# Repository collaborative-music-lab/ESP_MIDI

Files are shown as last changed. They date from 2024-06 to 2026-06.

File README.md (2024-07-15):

# ESP_MIDI
This repo contains hardware and software components for creating MIDI controllers using the ESP32-s3 microcontroller. The native USB port on the s3 allows for class-compliant MIDI devices which should be recognized natively by any computer.
The repo consists of:
1. **PCB**: A PCB design created in KiCad, along with PDF’s of the board and schematic
2. **Enclosure**: 3d-printable faceplates and knobs
3. **Software**: Arduino-based software for programming your MIDI controller
Each subfolder contains its own readme with additional information for each stage
# FYI / FAQS
There are several things you need to know.
### Allowing for class-compliant midi
To let ESP32-s3 appear as a class compliant device, you *must* set the ‘USB Mode’ for the board as “USB OTG(TinyUSB)”. You can find this setting in the Arduino *Tools* menu.
### Reprogramming after setting USB OTG
Once the board is set to USB OTG mode it won’t show up in Arduino as a Serial device. In order to reprogram the device you must manually hold down the ‘boot’ button on the ESP32-s3, and then press press and release the ‘reset’ on the ESP32-s3.
### Allowing for Serial debugging
In order to use serial.print debugging, you *must* set “USB CDC on boot” to “enabled”. You can find this setting in the Arduino *Tools* menu.

# Components
There are three components to this project:
1. The PCB and electronics assembly
2. The enclosure and mechanical elements
3. The firmware for the ESP-32-S3

Instructions on how to complete the project are in the readme's for these three subfolders.

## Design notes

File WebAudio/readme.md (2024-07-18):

# Web Audio using the 21M.080 Web Audio Framework

The 21M.080 Web Audio Framework is a live coding environment for working with audio in web browsers. This folder contains four files:
* SimpleSynth.txt: Gives a simple example of how to create a synthesizer
* Rumble.txt: A more complex synthesizer, which also includes a basic sequencer
* drum_sampler_midi.txt: An example of a drum sampler controller by our MIDI controller
* polyphonic_synth_midi.txt: An example using our MIDI controller to trigger four different pitch sequences

## Working with the framework

The website includes a codebox on the left hand side. You can execute code in three ways:
* Hitting the 'run' button will execute the whole codebox, from top to bottom.
* Putting your mouse cursor on a line and hitting option-return will execute a single line of code
* Putting your mouse cursor on a line and hitting shift-option-return will execute a block of code
  * Code blocks are separated by blank lines.
 
## Debugging
It can be really helpful to use the javascript console to see key information and any errors as you run code. 
* The javascript console can be found by going to the view menu, and then developer->javascript console. Or you can just type option-command-j

# Using a midi controller 
To use your midi controller with the framework: 
* copy and paste one of the files that say midi in the name into the codebox
* Hit 'run'
* Open the javascript console. If there are any errors try refreshing and running again
* With your MIDI controller plugged in, look for the midi inputs in the console. Your controller will show up as Wifiduino or something similar.
* Note the number associated with your controller in the list of inputs.
* In the codebox, there is a line `setMidiInput(2)`. Change the `2` to whatever number is associated with your controller and execute that line (option-return)
* Your controller should start triggering sounds!

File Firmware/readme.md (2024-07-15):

# Arduino Setup
Download the Arduino IDE from Arduino.cc
* there is a web app for Arduino but it won't support the ESP32 so we can't use it.

## Add support for ESP32 to Arduino
Add this link to:
* (MacOS) Arduino->settings->additional board manager URLs
* (Windows) File->preferences->additional board manager URLs
https://dl.espressif.com/dl/package_esp32_index.json

more info on this here: https://medium.com/@pauljoegeorge/setup-arduino-ide-to-flash-a-project-to-esp32-34db014a7e65

# Firmware
Two sets of firmware are provided

## InputMonitor.ino
This firmware allows you to monitor all of your input in the Arduino Serial Monitor
* MAKE SURE you set “USB CDC on boot” to “enabled”. You can find this setting in the Arduino *Tools* menu. The serial monitor will not work if you do not do this!

Once uploaded, open the serial monitor and you should see data streaming from all the sensors. Play with all of the sensors and make sure the data looks good. Take note of any of the potentiometers whose ranges are backward - we can fix this in the other firmware.

## ESP32_MIDI
This is the main firmware for the project, which sets up native USB-midi support. 

Open the ESP32_MIDI.ino file in the Arduino IDE. The comment at the top of the ESP32_MIDI.ino file should explain most of the code. All of the other files will open alongside the main file.

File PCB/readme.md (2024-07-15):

# PCB and Electronics Assembly

The project consists of:

1. The main PCB, with the ESP32 pre-soldered
2. 4 potentiometers, 2 to place on the PCB and two additional off-board potentiometers with small pcbs.
3. 4 Arcade Buttons
4. An LSM6DS3 IMU breakout board
5. An RGB LED and resistors

## Assembly

Make sure get your enclosure drilled for your faceplate before you mount your PCB to the faceplate in step 9!!!

1. Place two potentiometers on the PCB. Make sure they are flat. It is a good idea to place the potentiometers on a faceplate to make sure they are aligned. Solder the potentiometers in place.
	* the potentiometers go on the opposite side of the PCB from the ESP32 (e.g. the ESP32 is on the bottom, and the potentiometers are on the top).
2. The LED uses 3 resistors with values between 120 and 470 ohm. All resistors may be the same value. Place and solder the resistors. 
3. DO NOT solder the LED yet. We will solder the PCB once we are ready to mount the electronics to the faceplate.
4. Solder the small PCBs to the two off-board potentiometers. The potentiometer pins go in the holes next to the word 'POT'
5. Solder headers to the LSM6DS3 breakout on the side that has 6 holes. Leave the five holes on the other side of the PCB empty.
6. Place the LSM6DS3 breakout into the head holes labelled 'IMU' on the PCB. Make sure the V+ and VIN pins on the PCB and breakout are aligned. Double-check - if you are not confident, ask for help! 
	* The breakout should be on the bottom of the board, the same side as the ESP32
7. Cut wires for connecting the arcade buttons and external potentiometers. You will need 3 groups with different colors:
	* 6 wires for grounds
	* 6 wires for signal
	* 2 wires for V+
8. Solder these wires into the PCB. Note that there are six places for external sensors, each with a ground, V+, and signal pad. You will need to solder each ground and signal (A1-A6) pad, but only two of the V+/3v pads. 
9. Once all of these wires are soldered in it is time to mount the PCB in the faceplate and solder the LED. 
10. Put the LED in the LED holes. The longest leg of the LED goes into the round hole next to the square hole. If you look on the bottom of the PCB you will see one trace connected to the LED holes - that hole is where the long leg goes. 
	* It is a good idea to plug in your ESP32 and test the LED works before soldering it down
	* you will also need to adjust the LED so it fits through the hold in the faceplate before soldering it.
11. Once the LED is soldered you can screw the potentiometers on the PCB to the faceplate. Use a 10mm socket to screw this down.
12. Place the arcade buttons and other potentiometers in the faceplate. Make sure the faceplate fits inside the enclosure
13. Solder the wires to the potentiometers. Look on the small PCB and you will see indications for where G, V+, and Sig go.
14. Solder wires to the Arcade buttons. These just have a ground and signal wire soldered to the two pins. It doesn't matter which pin is ground and which is signal.
15. You are done soldering! Time to program the ESP32 and test your MIDI controller. You might want to hold off on screwing the faceplate down until you have tested all of the sensors. . .

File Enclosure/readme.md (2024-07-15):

# Enclosure

All 3D printed files were created with the free open-source CAD software Blender - download here:

## Faceplates
The enclosure is designed to use a Hammond 1590BB Aluminum enclosure, with a 3D-printed faceplate. Two faceplate designs are provided in the faceplates folder.

## Knobs
The project uses standard 7.3mm knurled potentiometers, and a series of 3D-printed knob designs are available:
1. `_knurledKnobInsert_7.3mm` is a file of a standard knurled potentiometer shaft, and can be used to create your own knob design
2. `knurledKnobDome_20mm-Dome` is a large knurled dome knob
3. `knurledKnobFlatWide_18mm-Circle.stl` and `knurledKnobFlatWide_20mm-Main_body` were created to make it easy to turn a knob with one finger. These designs are full-height and meant to work with standard enclosure.
	* `knurledKnobFlatWide_20mm_pointer-Pointer` is a small shape inset into the top of the above knobs to use as a pointer
4. `knurledKnobFlatWide_20mmTop_rounded-Circle` and `knurledKnobFlatWide_20mmTop-pointA-Circle_001` are half-height knobs, intended to be used with recessed potentiometers. 
	* `knurledKnobFlatWide_20mmTop-pointB-Circle_001` is a pointer for these knobs.
	
## USB-C port
This is a cap meant to be used to cover the hole drilled for the PCB's USB-C jack. It is oversized to allow a cable to pass the the cap.

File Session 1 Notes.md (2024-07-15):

Introduction to music technology and essential concepts
1. Introduction 
   1. Who is a music technologist?
   2. What do we need to know?we will be talking about what sound and music consists of 
   3. I am a musician first and technologist second 
      1. everything you learn will be important whether you are a musician performing with technology or someone creating your own new technology to make music
2. Fundamental concepts
   1. Learning the languageWhat is sound harmonics amplitude frequency 
3. names for pitch, frequency, midinote, chord degree
4. What is an octave frequency, ratios, harmonics, and pitches? ￼
5. Visualization 
6. Frequency spectrum is and frequency responses. ￼
7. Sounds and time envelopes, rolloff, etc. also revert and delay. ￼
8. Playing with synths 
9. ￼ what is digital audio, sampling rate bit depth, audio interfaces 
10. using plug-ins working with EQ and compression ￼￼
11. Mastering using speakers and the entire recording chain. ￼

# Introduction
Who is a music technologist? I would say anyone who is creative, musical ideas are expressed through new electronic or digital systems from any of us. This will involve learning how do use new systems being aware of what the new possibilities are in integrating them into our musical performance practice however, increasingly it is common for musicians to actively create new technologies as part of their creative process. For me, this is one of the most exciting aspects of being a contemporary musician.

Here are some examples of work you might engage in:
* recording music entirely within a digital audio workstation
  * you might use a MIDI controller as an input device, or work solely with your laptop
* building a personal sample library for performance or composition
  * this involves either recording your own sounds, or finding sounds only and processing them
  * your personal musical tastes and goals will cause you to be highly selective, and you will likely manipulate all of the samples in your library to get them to sound just right
* building synthesizers, or other musical instruments, inspired by current instruments
  * many people are inspired by existing instruments, either wanting to improve on them, or combine them, or just build something that you can't get your hands on any other way
* designing new kinds of instruments, inspired by your own ideas
  * sometimes you'll have an idea for a new instrument that you've never seen before. Exploring your own ideas in this way, can be highly satisfying and lead to very unique music.
* designing new forms of musical performance using sensors
  * all hardware instruments rely on sensors to detect gestures. There are lots of sensors out there and also lots of different ways of making mechanical structures to work with the sensors. It can take a long time to get a sensor to feel just right!
* creating tools to generate music
  * AI has gotten a lot of attention for generating music in the past few years, but people have been creating generative music processes for centuries. Many musicians have specific generative processes that they rely on as part of their practice, and get to know extremely well. Generative music does not have to be an all or nothing deal, you can have a generative system create only part of the musical texture, and then control or compose the other parts of yourself. As you can imagine, there are lots of possibilities, and they can be really fun!
* creating tools to analyze music
  * Similarly, there has been a lot of attention on music analysis in the past few years. Music analysis lets the computer understand what is going on within a musical structure in the same way that a human might hear it. This makes it possible for a computer to compare pieces of music, identify genres tempos or other musical elements, learn the underlying patterns in a musical piece in order to create similar pieces, etc. 

These are only a few examples of work within music technology – there are many others, anything, which lets you explore your personal fascination with music and sound through a computer!

# Learning the Language pt 1.

Music technology brings together people from lots of different fields, including performers and composers, acoustic engineers, software programmers, electrical engineers, hardware designers, UX designers, human-computer interaction researchers, cognitive scientists. . . . the list goes on! All of these people work with the same fundamentals of music, but often talk about it in different ways. We will need to learn the language of music technology to help us understand how the same concepts can be thought of in different ways.

##  Visualizing audio
It is helpful to have a visual representation of audio. There are two common ways by do this, looking at audio in the time domain using an oscilloscope, or looking at audio in the frequency domain using a spectroscope.

### Oscilloscopes
Oscilloscopes are a tool to analyze signals used within electrical engineering. The nice thing about them is they are able to give us a representation of what an audio waveform actually looks like in the air. Generally speaking, oscilloscopes show amplitude in the Y axis, and time in the X axis. Because sound moves really fast and we might want to zoom in or zoom out in both axes. You will notice that the sound continues to travel from left to right.
### Spectroscopes
Spectroscopes are used to show the frequency content of sound. We will take a look at what that means in the moment. There are several kinds of spectroscopes that you will see. Some of them will represent frequency on the x-axis and amplitude on the Y axis. But there are also special tools called Spectrograms that try to combine time, amplitude, and frequency. 
## Pitch & Frequency
When you ask people what they think the most fundamental aspect of music is, they will often say musical pitch. When a young musician first picks up an instrument, they will often begin by playing a scale. What are the terms we use to describe a musical scale?

1. *Note Name*: a letter or a word used to refer to a specific pitch, such as “Middle C”, “High G”, or “Sol”. Music theorists will often include the octave number, such as C3 being an octave lower than C4.
2. *Harmonic Interval*: the way in which a note relates to the harmony, a piece of music, such as the tonic, 5th, or leading tone.

We might think that understanding how to name musical pitches gives a strong foundation for understanding music, but in reality is that what the name of a musical pitch means can vary. Different cultures refer to notes with different words, different styles of music think about pitches in different ways, different traditions use different kinds of notation, and particularly how a pitch relates to a frequency can be almost totally arbitrary.
### Frequency
Fundamentally, pitch is a construct that musicians agree on in order to communicate with each other. This is very different from the *frequency* components of music.

Frequency is a measurable characteristic of sound, something that has a firm basis in traditional physics, and will be consistent throughout the world. Put very simply, the frequency of a waveform is the of number of repetitions of a waveform within one second. In fact, the earliest name for musical frequency is simply cycles per second (cps). This name is still used within certain disciplines. 

However, most of us use the term *hertz* as the unit of frequency, abbreviated as hz or khz for kilohertz. The lowest note on a guitar is generally ~83Hz, middle C on a piano is 261.63 hz, and the highest sound a human can hear is generally ~20khz.

So, how is frequency different from pitch? A couple of key ways:
* because frequencies are measurable they are consistent. The frequency that pitches refers to can very, for example A equals 440 Hz or A equals 432 Hz.
* we generally compare two frequencies by looking at the ratio between them. Because both frequencies are fixed, the ratio is also fixed. In musical tuning systems, however, the distance between two pitches may refer to different ratios. This is referred to as using different intonations.
* there are a relatively small number of pitches within most musical systems, whereas frequency and represents any musical sound.
### Sine waves
We often think about calculating frequency in terms of the simplest waveform, a sine wave. 

What do we mean when we say that a sine wave is the simplest waveform? If you take a look at any arbitrary waveform you might notice that it looks very complicated with lots of peaks and valleys that are continually changing. But it turns out that these complicated waveforms can be created by simply adding together lots of sine waves. That is to say that every complex wave forms consists of a bunch of simple sine waves. 

We can understand this better by taking a look at how a few more complex but still fairly simple waveforms can be created using sine waves. Common waveforms we might see like this are triangle waves sawtooth waves, and square waves. Each of these can be created by something together a series of sine waves.

### Harmonics
While any sound can be thought of as a combination of sine waves, simple waveforms are a special case in that all of the sine waves that are present fuse together into a single shape, and also a single pitch. This causes each waveform to have a slightly different sound. which we refer to as *timbre*. 

The way that we create waveforms is by combining a bunch of sine waves that are integer multiples of the *fundamental frequency.* The fundamental frequency is the lowest frequency that is present, and every other frequency, it must be an integer multiple of that fundamental. These integer multiples are called harmonics, and they are present in any sound of that has a single strongly defined musical pitch.

For example, if the fundamental frequency of a waveform is 100 hz, the harmonics will be 200, 300, 400, 500, 600, etc. 
### Octaves
We already mentioned how important it is to be able to compare the distance between two frequencies. Partly this is because it is very common for music to have more than one pitches played at the same time. The most basic relationship between two pitches is that of the octave. 

From a frequency perspective, an octave is a doubling of frequency. So the octave of 110 Hz (A2) is 220 Hz (A3), and the octave of 200 Hz (A3) is 400 Hz (A4). If you look at this for a second, we will see that two octaves above 110 Hz is 440 Hz.  This shows us that our perception of pitch is nonlinear, that is the distance in an octave will change, depending on where it is located in the frequency spectrum.

If we continue following the above octaves we get: 880 hz (A5), 1760 hz (A6), 3520 hz (A7), 7040 hz (A8), 140080 hz (A9). Any higher than this and we won’t be able to hear it. Notice that means that the highest octave we just described has a distance of 7000 Hz, versus just 110 Hz between A2 and A3.
 
Another implcation of this is that all the other intervals in a musical scale are similarly nonlinear. 
# Exploring synthesizers
Take a moment to play around with a synthesizer, either a hardware synthesizer, or a software synthesizer. Look for the controls that affect the frequency of the sound. You might also consider what other aspects of the sound you can change, for example, the loudness of the sound, or the quality of the sound. 
# Learning the Language pt. 2
## Volume & Amplitude
Another common characteristic of sound is how loud it is. The typical way of talking about loudness is volume. Volume is just a perceptual description of our current experience of loudness levels, but in fact our perception changes strongly based on our environment. If we are at home in bed, something that sounds very loud to us might not sound nearly as loud if you are sitting in a noisy restaurant.

### Amplitude
Amplitude is the part of the waveform that affects our perception of volume. Very simply amplitude is a measurement of how far a waveform deviates from its midline. The taller or larger is a deviation is. the louder the volume of a waveform will be. There are two common ways of referring to amplitude.

When working with digital audio, particularly when programming, we often refer to the amplitude of a wave form as ranging between -1 and 1.  Notice that we are using zero as the middle line of our waveform. This makes sense because all sound is an alternating wave form that periodically moves up and down and revolves around a single middle line. When you look at the raw data of an audio file, you will find that all of the amplitudes are within this range of [-1, 1]. 

The other way of referring to amplitude is by using decibels (or dB). (If you think about that for a second, a Bel is the actual unit, but we will always refer to deci-Bels, hence decibel and dB). A decibel is a handy unit because it takes into account that, just like frequency, our perception of amplitude is nonlinear. In fact, we have to more than double the amplitude of a signal in order for it to sound twice as loud. 

The most important number to know when thinking about decibels is that 6dB is a doubling of measured amplitude.

### Decibels Full-Scale
Remember, how frequency is related to the number of cycles per second? That per second gives us a constant reference we can compare to. Similarly, we need to use a constant reference in order to compare our sound’s amplitude in order to get a measurable result. It turns out that there are actually a variety of decibel formats, depending on whether we are measuring sound in  air (dB Sound Pressure Level or dB SPL), sound as an electrical signal (dBV), or inside a computer (dBFS). 

Focusing on the computer side of things, decibel full-scale or **dBFS** represents amplitude in terms of the highest possible amplitude able to be represented within a computer given a certain number of bits used to represent that amplitude. For 8 bit audio there are a total of 256 possible amplitude levels. The highest amplitude (255) would have a value of 0dBFS, and every other amplitude level would be represented as a negative number. For this reason, dBFS always consists of negative numbers.

The one exception to this is when using dB to come here to arbitrary audio signals. For example, it is common to say you increased the amplitude of a sound by 6 dB, meaning, you doubled its amplitude compared to its previous amplitude.

## Timbre, tone quality, and frequency spectrums
Now we can talk about sound in terms of its frequencies, it's amplitude, and the relative amplitude of the different frequencies within the sound. We already saw Hall combining frequencies at different amplitudes can let us create different waveforms. It turns out that all of their difference between sounds can be described in just this way. 

What makes my voice sound different than your voice? Why does a flute sound different than a trumpet? How can we tell the difference when we knock on a piece of wood versus a piece of metal?

All of these perceptions are possible because we understand on the deep level how frequencies combine to make a sound. Frequencies that are harmonics will create musical pictures that are very clear. Frequencies that are not harmonic (or inharmonic) will cause, dissonance, noise, or complexity.

### Timbre
Timbre (pronounced tam-brr in american english) refers to the quality of a sound. We might say an instrument has a nice timbre, or a woody timbre, or a harsh timbre. Timbre can mean much the same thing as tone quality, or musical tone in other contexts. 
### Frequency spectrum
While timber is a qualitative term, we can describe it in terms of the frequency spectrum of a sound. The frequency spectrum is simply a representation of all of the frequencies that are present within a sound, and their various amplitudes. Using a spectroscope, we can clearly see the difference between the frequency spectrum of different vowels.

Everything in the world that can create or respond to sound has a *frequency response*. This frequency response illustrates how an object or system will affect the frequency spectrum of the sound that it creates or the sound that a processes. We might say that when we send audio through a system that has a flat frequency response, the output is the same as the input. But in reality, there is no such thing as a flat frequency response. Everything has some kind of response, and generally has an audible impact on the sound as it passes through it.
### Timbral evolution
Something that will become very apparent when looking at a spectroscope is that the frequency spectrum of a sound does not stay constant. This is true in almost all contexts. Because this is such a fundamental aspect of sound, we are very sensitive to changes in timbre over time and they play an important role in our musical perception.

The most basic way of thinking about timbral evolution is when you play a note on an instrument. When you pluck a note on a string, for example, there is a brief moment, when the note is first plucked when it is at its highest amplitude. At this moment it is also at its brightest, that is the highest components of the frequency spectrum are relatively loud. As the sound progresses over time, the higher frequencies become quieter and less perceptible. This is characteristic of many kinds of instruments, including pianos, drums, string instruments of all sorts, mallet instruments, even trumpets and wind instruments when they are strongly tongued. 

### Envelopes
One way of expressing this evolution overtime within synthesizers is through the use of envelopes and filters. A filter is used to modify the frequency spectrum of a sound. The most common kind of filter is a lowpass filter, which allows low frequencies to pass while filtering out higher frequencies. Generally, speaking, filters that don't change are not that interesting. 

What makes filters much more interesting is when they change over time as a sound progresses. This is much like how the higher frequencies and a string die out overtime. To do this, we control the frequency of a filter using an envelope. The envelope starts with an amplitude of zero, and then when a note is played,the envelope’s amplitude increases to one and then gradually falls back to zero. When the envelope is used to modify the frequency of a filter, it will make an audible change, allowing the higher components of a sound through at the beginning, but filtering them out as the sound progresses. When an envelope is used to modify the amplitude of a sound, it will make the sound louder at the beginning of the note, and gradually fade to silence.

### ADSR Envelopes
Amplitudes will generally have controls for how fast the amplitude goes from 0 to 1 and then back down to zero again. The rise from 0 to 1 is called the attack of the envelope, or the rise time. This is often quite short for plucked or struck instruments. What happens after this point varies depending on what kind of instrument we are playing.

The most common kind of instrument we might emulate is a keyboard instrument. With keyboard instruments, you strike a note and then hold it for a period of time before releasing the note. When you play a note on the piano, you will hear a quick rise, and then a gradual fade to what we called the sustain level of the piano, where the note continues to ring with relatively little change in amplitude. When you release your finger from the key, the sound then goes from this is sustain level to silence.

To represent this in synthesizers, we use something called an attack-decay-sustain-release (ADSR) envelope. 
* The attack time represents that sudden rise in amplitude
* The decay time represents how long it takes for the amplitude to fade to the sustain leve
* The sustain is the amplitude of the sustain level. In an ADSR envelope the sustain is a fixed value, while in a piano this sustain does actually have a gradual fade.
* The release time determines what happens when a key is released. At this point, the sound goes from its current amplitude 20 over at the duration of the release time.
There are several other kinds of envelopes out there, including an attack-sustain-release envelope, and attack-release envelope, etc. 
But if you understand an ADSR envelope then every other envelope is relatively simple.

# Exploring synthesizers
Take a look at a hardware or software synthesizer, and look for the elements of the synthesizer used for changing the timbre and the envelope of the sound. Envelopes will generally need to be triggered in someway, either by a keyboard or a sequence, or sometimes just by pushing a button.

# Digital Audio
Everything we have talked about so far generally refers to audio in all of its different forms. But for the most part we work with sound in a digital forum at this point, so it makes sense to understand how we represent sound digitally. Luckily, it is quite simple.
## Digital sampling
The biggest change is that we are going to move from a continuous or analog signal to a discrete or digital signal. Remember how a sound wave on an oscilloscope has time on the X axis and amplitude on the Y axis. To turn this into a discrete signal we will have to discretize both time and amplitude.
### Sampling rate
The time dimension of sound and digital audio is chopped up into what we call samples a sample is simply a representation of the amplitude of a wave form at one moment in time the rate at which we capture samples is called the sampling rate.
* Sample: the amplitude of a sound wave at one discrete moment of time, generally represented from -1 to 1
* Sampling rate: the number of samples we measure per second, generally represented in kilohertz
If you zoom in on a waveform, you can often find dots or values representing the amplitude of the individual samples. The magic is that if you create a sound wave that smoothly changes between these values at the same rate as the sampling rate you will perfectly reconstruct the sound that was sampled with no noticeable change in total quality.

To say that again, if you take a sound wave, convert it to digital, and then convert it back to an analog sound wave you will not be able to hear any notice in the sound. Sound like an impossibility? Well, assuming a microphone, and speaker that both have flat frequency responses then this will be true. (Of course, we know that there is no such thing as a flat frequency response so this is not quite true, but let's ignore that for the moment).
### Nyquist frequency
There is one giant caveat here, and that is that the highest frequency of the sound he wants to sample must not be higher than half of the sampling rate. We know that the highest frequency that humans can generally hear does not exceed 20kHz. Therefore, frequencies above that in generally be ignored. This means that a sampling rate of 40kHz or higher should be sufficient for most audio. In fact, most sampling rates are either 44.1 kHz or 48 kHz.
### Bit depth
The other consideration in digital audio is how many bits we use to represent amplitude. The reason why this is a little bit of a big deal is the more bits we used to represent amplitude the larger the file sizes that we generate, and the more processing it takes to generate audio. Back in the old days, eight bit audio was often used, actually affected quite a bit of a nostalgia for eight bit audio. When digital audio became of available on CD, the bit depth went from 8-bit (0-255) to 16-bit (0-65535) which increase the fidelity of music so much that we generally consider 16 bit audio as having a wider dynamic range than we can perceive. 

There are higher bit depths that computers use now, which can decrease the likelihood of complex processing affecting the sound of negatively, and also make it marginally more CPU intensive to work with audio. But for all practical purposes, 16 bit is good enough.
# Use cases of all of the above 
1. Acoustic instrument construction: stradivarious
2. Electronic synthesis techniques: east-coast vs west-coast
3. Lo-fi audio: vinyl vs digital
4. Loudness wars

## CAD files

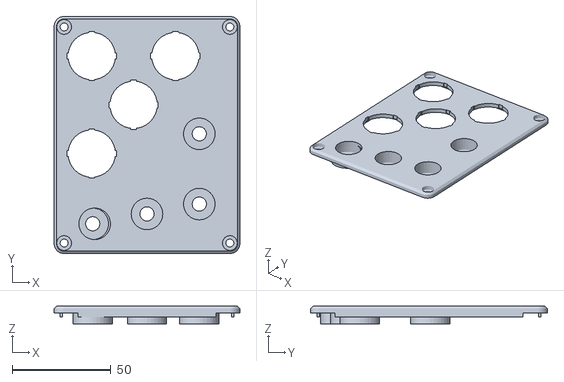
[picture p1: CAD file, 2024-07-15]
Enclosure/Faceplates/1590BB_cover3b-noLed.stl
94.1 x 120.1 x 8.88

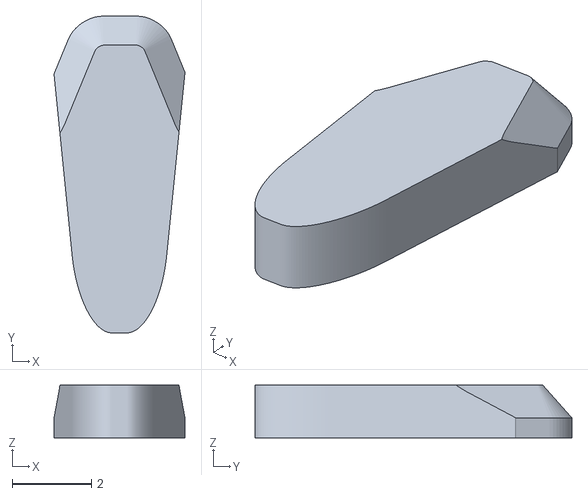
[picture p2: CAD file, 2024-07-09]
Enclosure/Knobs/knurledKnobFlatWide_20mm_pointer-Pointer.stl
3.31 x 8.01 x 1.34

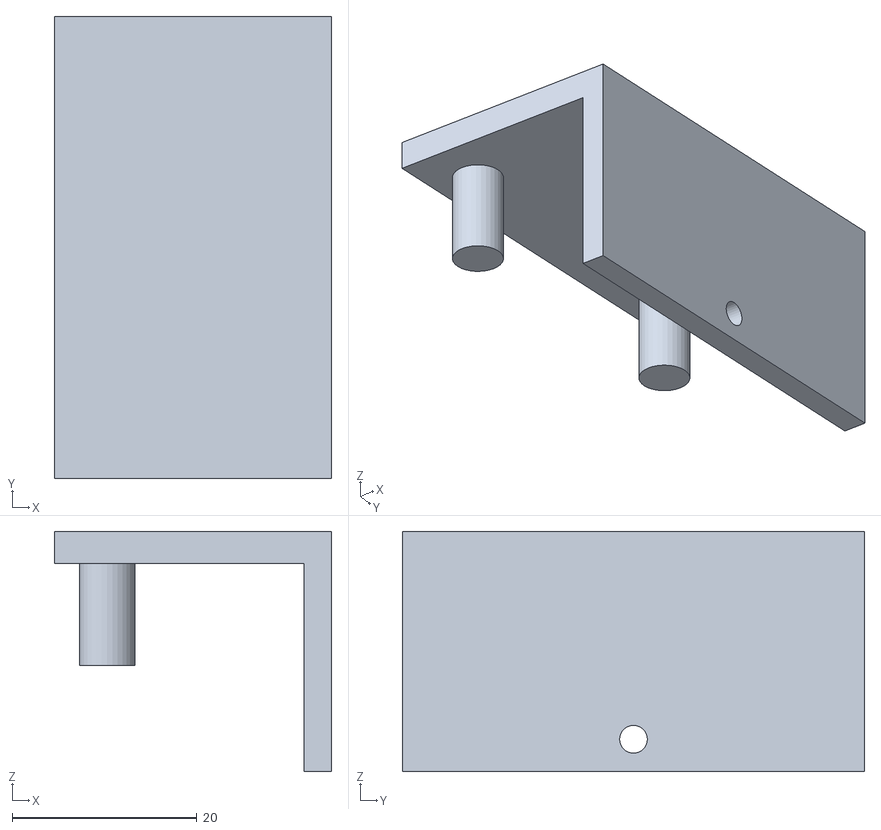
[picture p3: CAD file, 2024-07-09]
Enclosure/MIDI_jig-Cube.stl
30.0 x 50.0 x 26.0

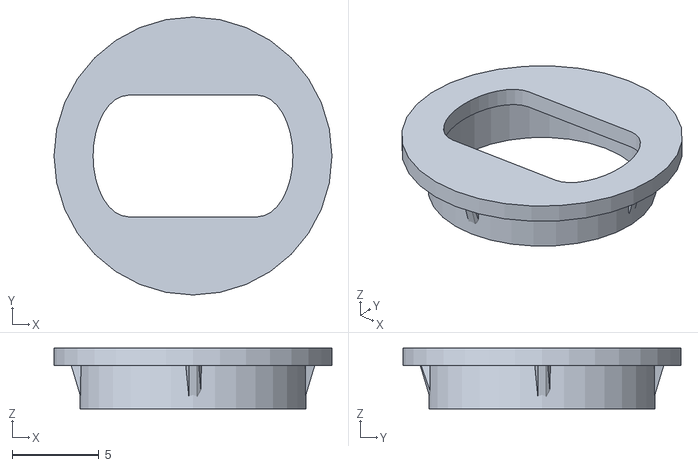
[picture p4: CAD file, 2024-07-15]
Enclosure/USB-C port/USB-C_port_13mm-Port.stl
16.0 x 16.0 x 3.50

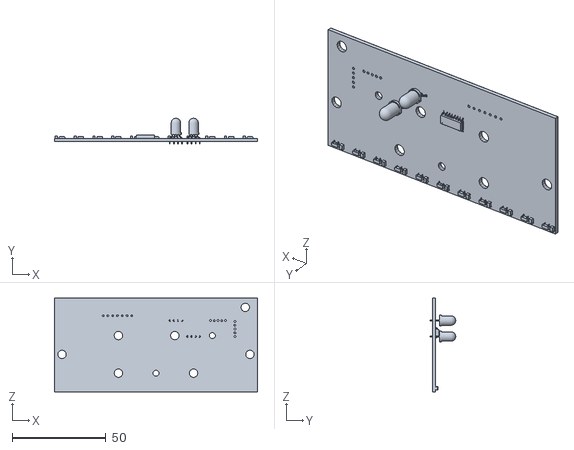
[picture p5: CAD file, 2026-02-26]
PCB/Kicad/DC12v/mbriaPCB_v0_1-SHAPE_476_IndexedFaceSet.stl
108.0 x 13.6 x 50.0

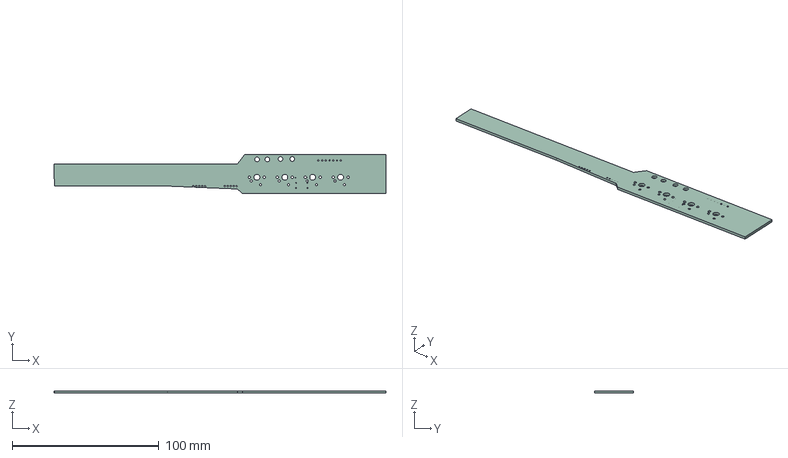
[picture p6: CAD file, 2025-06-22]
PCB/Kicad/ESP32_laptop-midi/ESP32_MIDI_WAND.step
226.6 x 26.5 x 1.60 mm

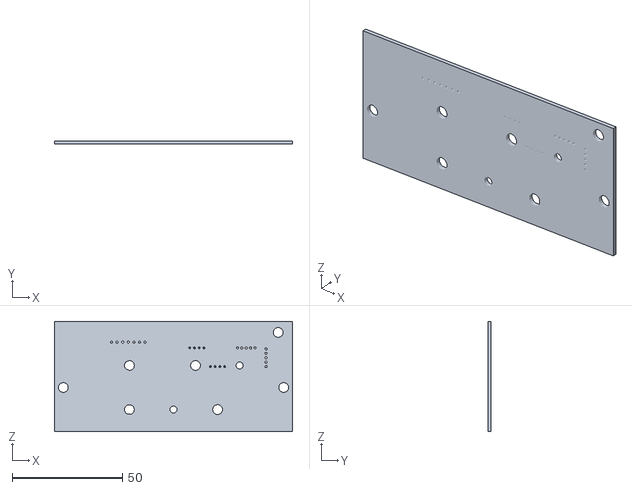
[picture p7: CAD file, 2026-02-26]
PCB/Kicad/ESP32_S3_Adaptor/mbriaPCB_v0_2-mbriaPCB_v0_1-SHAPE_476_IndexedFaceSet.stl
108.0 x 1.51 x 50.0

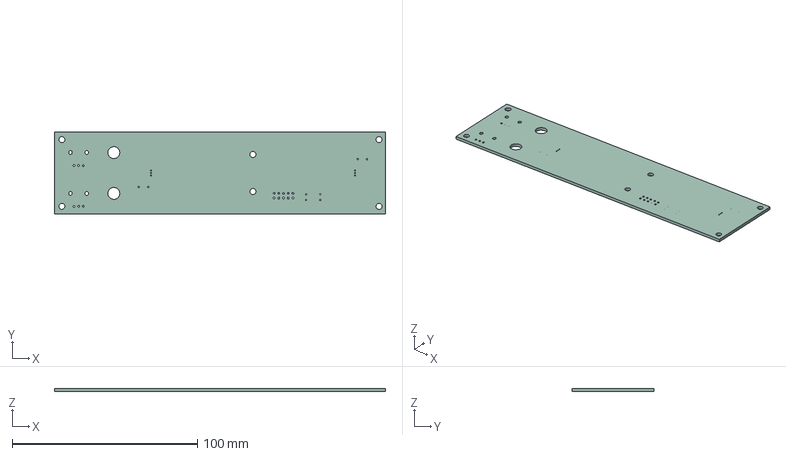
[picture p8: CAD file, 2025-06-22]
PCB/Kicad/Main-PCB/ESP32_MIDI_Summer25_FRETS_v2_5.kicad_pcb/ESP32_MIDI.step
178.5 x 44.0 x 1.60 mm

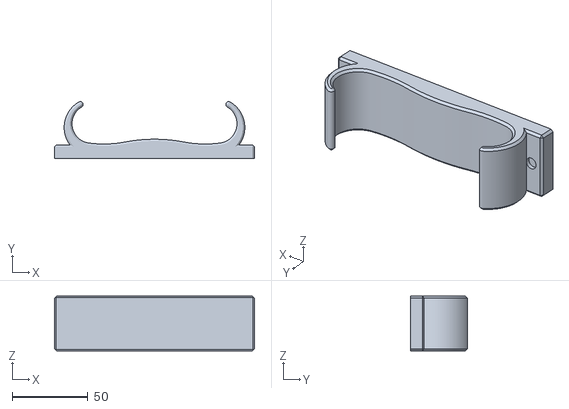
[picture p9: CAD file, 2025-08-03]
PCB/Kicad/Main-PCB/Sum25_GTR/Enclosure/Barre hooks V3.stl
132.0 x 37.5 x 36.0

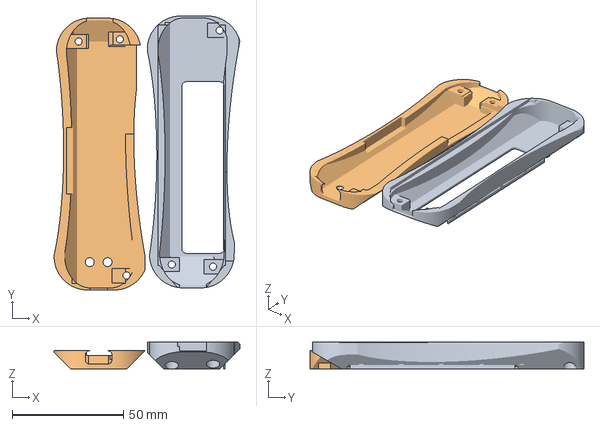
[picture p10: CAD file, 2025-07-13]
PCB/Kicad/Main-PCB/Sum25_Wand_v2/Wand.3mf
83.4 x 122.9 x 11.9 mm
_changes - 2025-07-11T112028.828.stl
_changes - 2025-07-11T112041.234.stl

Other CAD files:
Enclosure/1590BB.stl
Enclosure/Faceplates/1590BB_cover3-Top_002.stl
Enclosure/Faceplates/1590BB_cover3b-LED.stl
Enclosure/Knobs/knurledKnob2.blend
Enclosure/Knobs/knurledKnobFlatWide_20mmTop-pointB-Circle_001.stl
Enclosure/MIDI_PCB.stl
Enclosure/USB-C port/USB-C_port_13mm.blend
Enclosure/arcade_button_23mm.blend
Enclosure/arcade_button_23mm.stl
Enclosure/arcade_button_29mm.blend
Enclosure/arcade_button_29mm.stl
Enclosure/pot_RK07.stl
PCB/Kicad/DC12V_A/mbriaPCB_v0_2.blend
PCB/Kicad/DC12V_B/mbriaPCB_v0_2.blend
PCB/Kicad/DC12v/mbriaPCB_v0_2.blend
PCB/Kicad/ESP32_S3_Adaptor/mbriaPCB_v0_2.blend
PCB/Kicad/Main-PCB/ESP32_MIDI_Summer25_FRETS_v2_5.kicad_pcb/GTR.blend
PCB/Kicad/Main-PCB/Sum25_GTR/Enclosure/Fret Stands.stl
PCB/Kicad/Main-PCB/Sum25_GTR/Enclosure/Hooks V5 (1).stl
PCB/Kicad/Main-PCB/Sum25_GTR/Enclosure/One Bar Hook.stl
PCB/Kicad/Main-PCB/Sum25_GTR/Enclosure/Triple Brace V1.stl
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

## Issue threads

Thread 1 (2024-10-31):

Can you upload image of pcb and case?

DRCRecoveryData, 2024-10-31:
Hi,

Can you upload image of pcb and case?

Also does ADC of potentiometers from your code is 7 bit or 12 by default?

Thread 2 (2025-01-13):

How do you set the name of the MIDI device?

spDuchamp, 2025-01-13:
First of all, THANK YOU!!!   I've been totally stuck trying to get USB MIDI working on an M5Stack AtomS3 for weeks, and your project was the first thing I've found with a clear set of instructions and working code that has managed to get this prototype to connect properly as a USB MIDI device.

My little prototype controller when it connect shows up as "M5STACK_ATOMS3". How can that string set?

ianhattwick, 2025-01-13:
Ha - glad it helped!

I haven’t looked into changing the name - let me know if you find a solution!

-ian

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

spDuchamp, 2025-01-13:
Will do.

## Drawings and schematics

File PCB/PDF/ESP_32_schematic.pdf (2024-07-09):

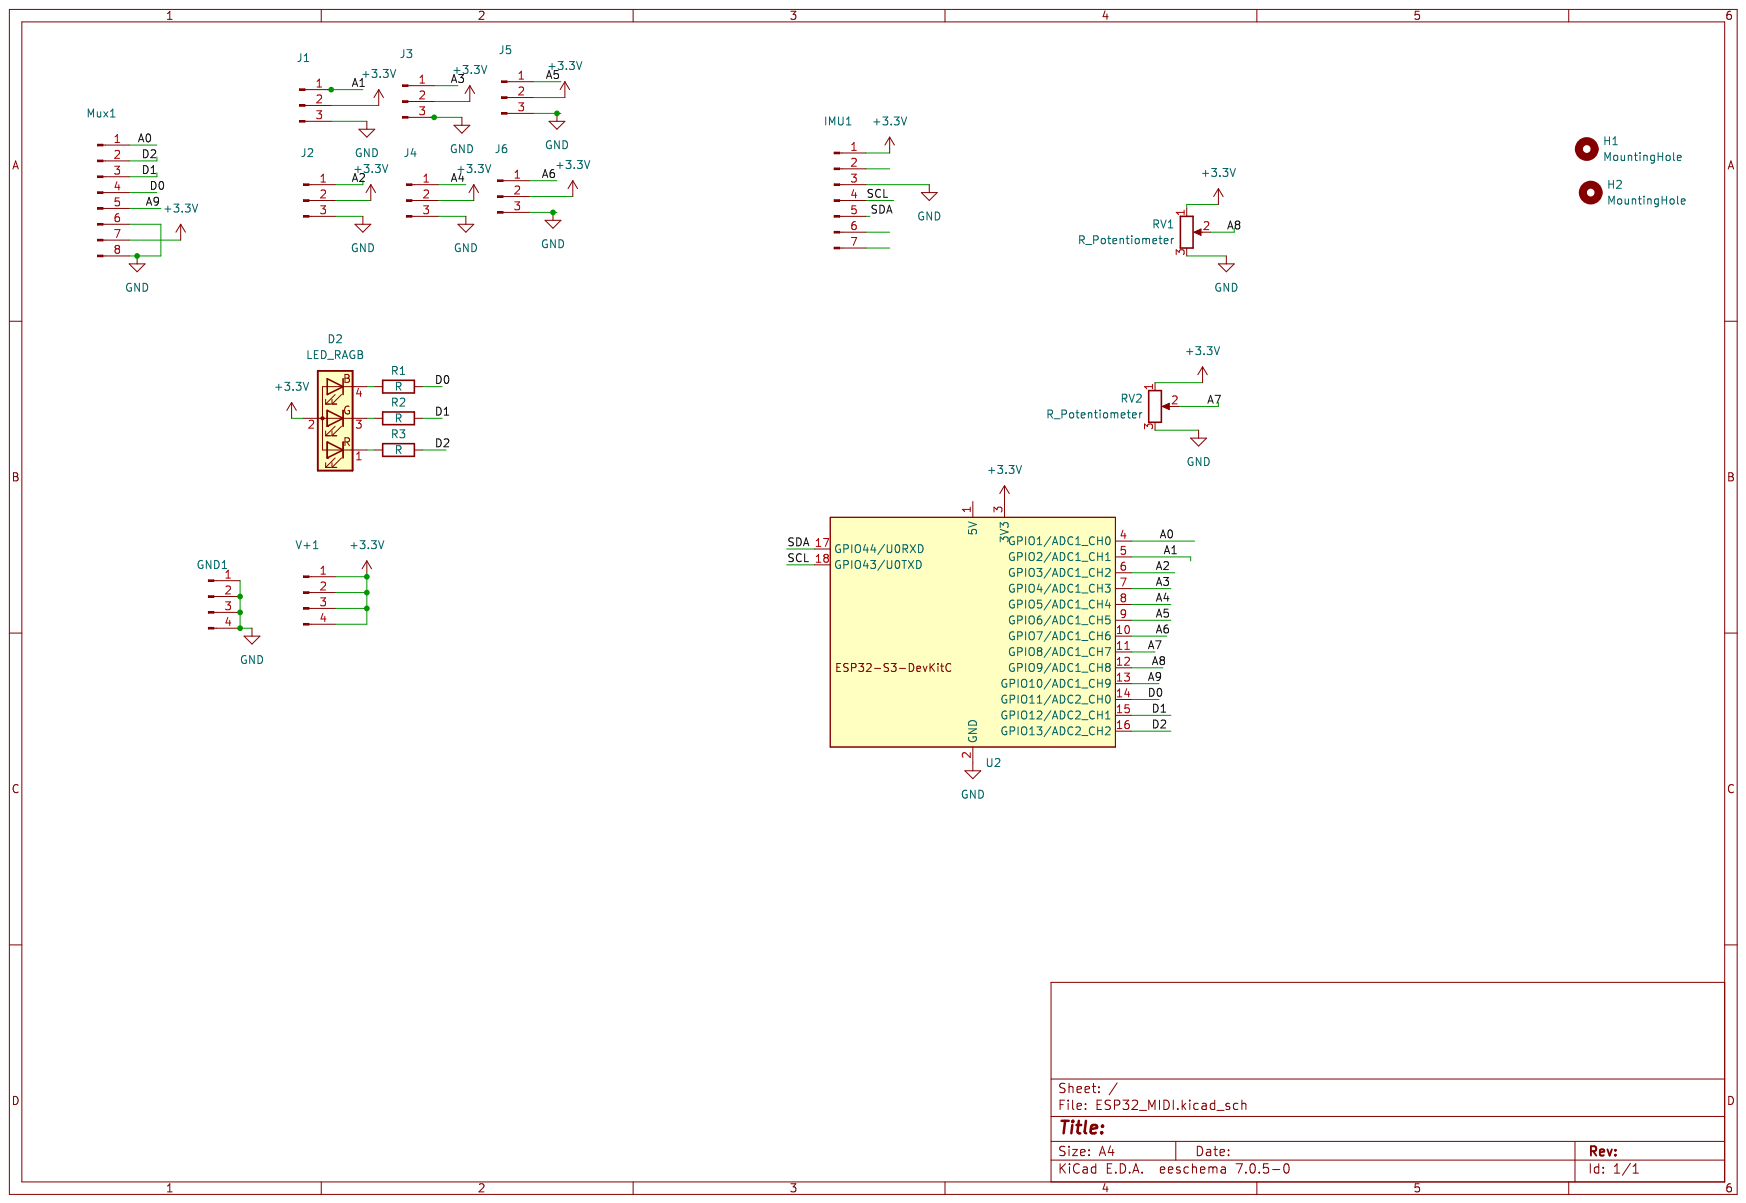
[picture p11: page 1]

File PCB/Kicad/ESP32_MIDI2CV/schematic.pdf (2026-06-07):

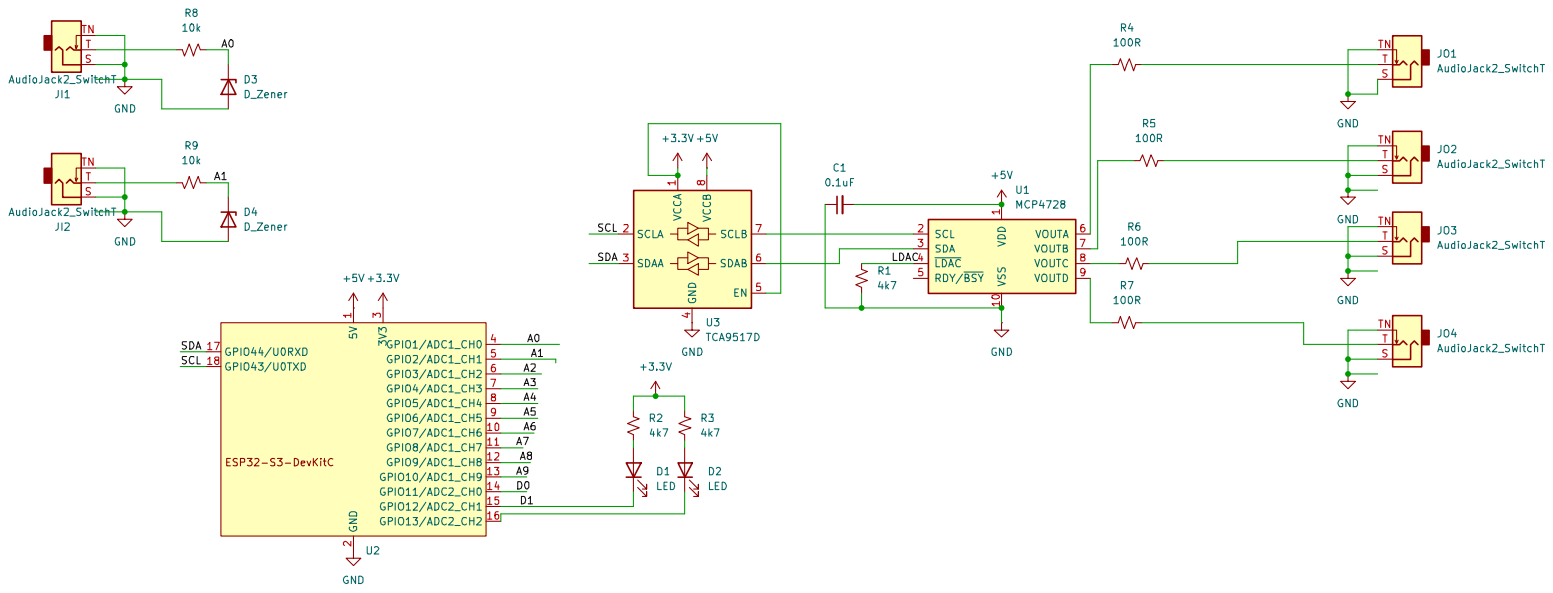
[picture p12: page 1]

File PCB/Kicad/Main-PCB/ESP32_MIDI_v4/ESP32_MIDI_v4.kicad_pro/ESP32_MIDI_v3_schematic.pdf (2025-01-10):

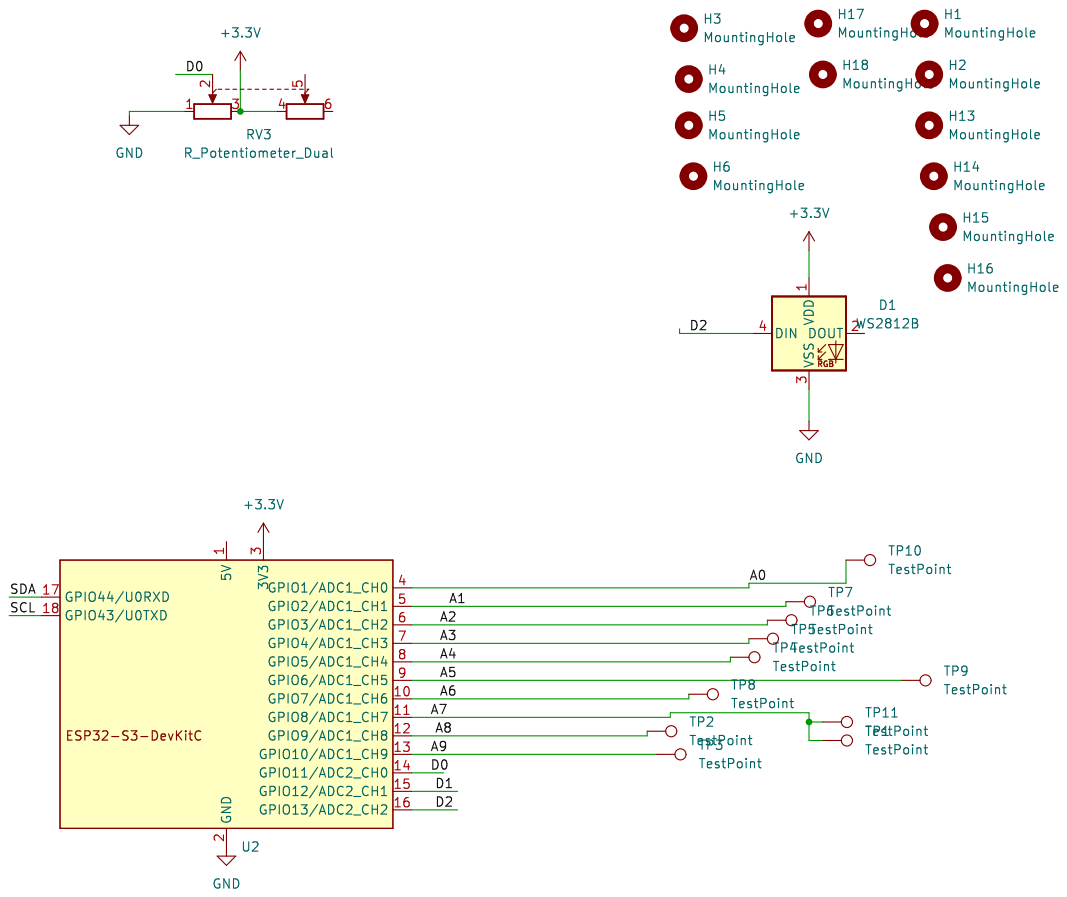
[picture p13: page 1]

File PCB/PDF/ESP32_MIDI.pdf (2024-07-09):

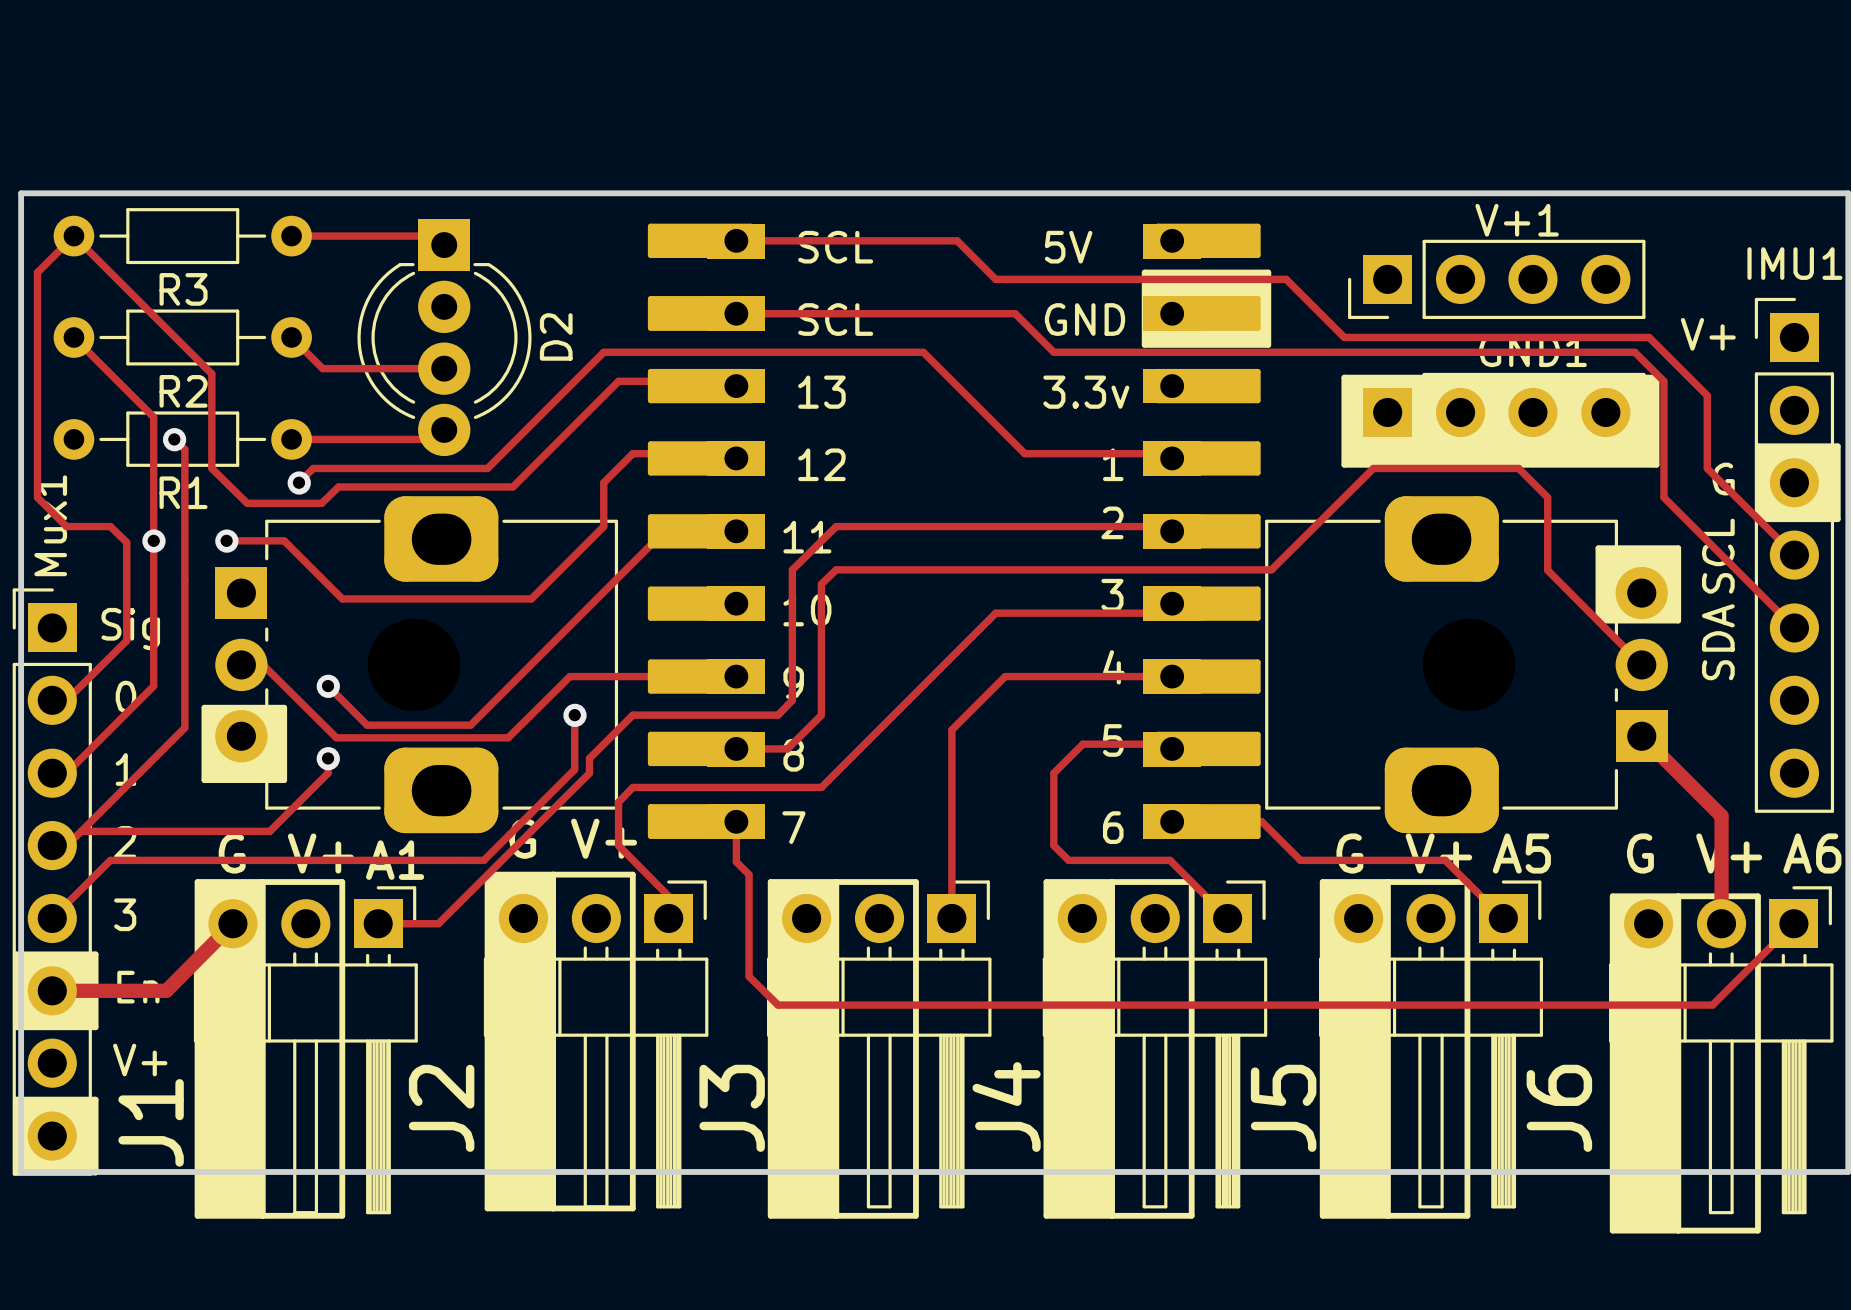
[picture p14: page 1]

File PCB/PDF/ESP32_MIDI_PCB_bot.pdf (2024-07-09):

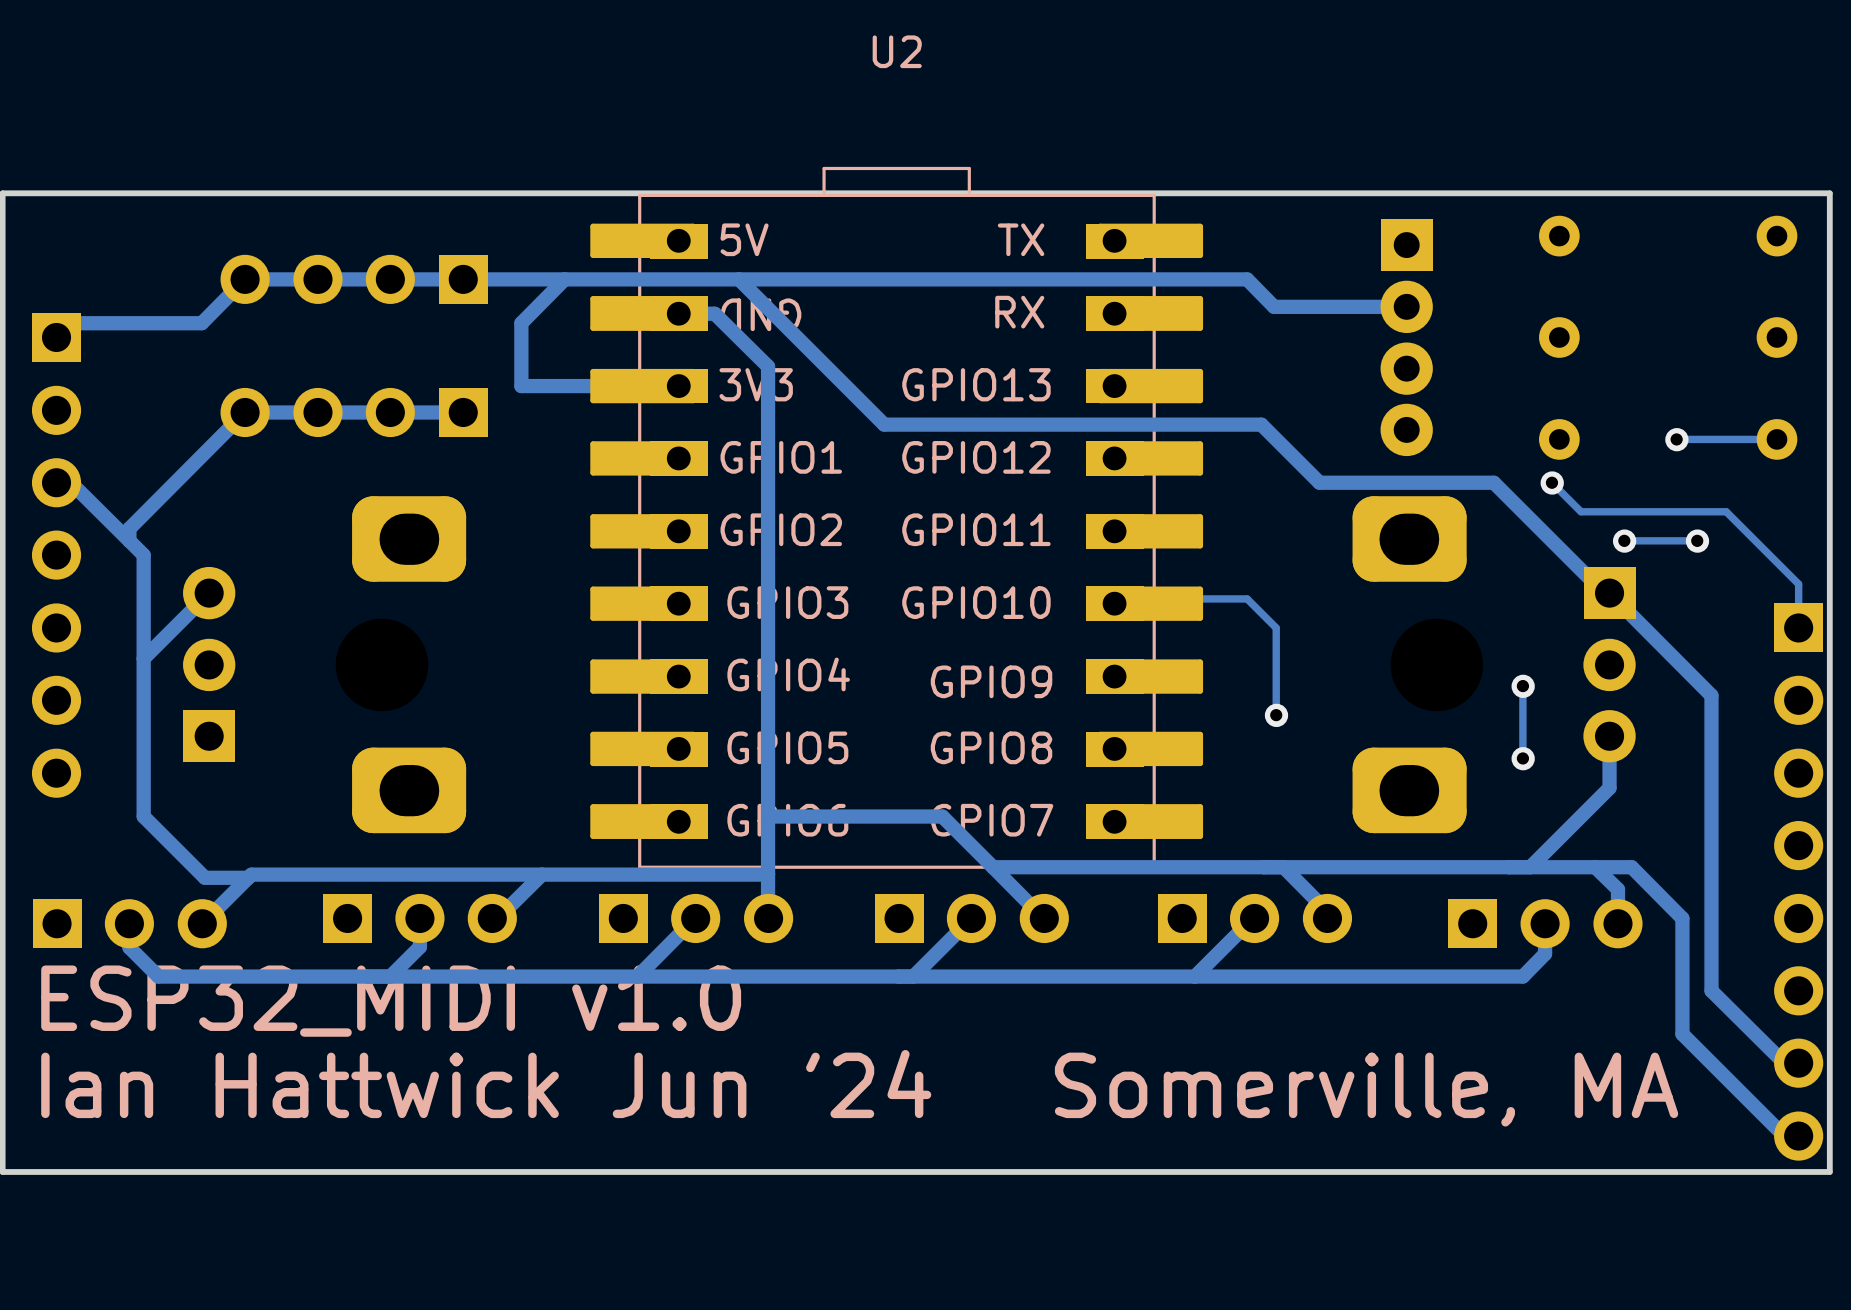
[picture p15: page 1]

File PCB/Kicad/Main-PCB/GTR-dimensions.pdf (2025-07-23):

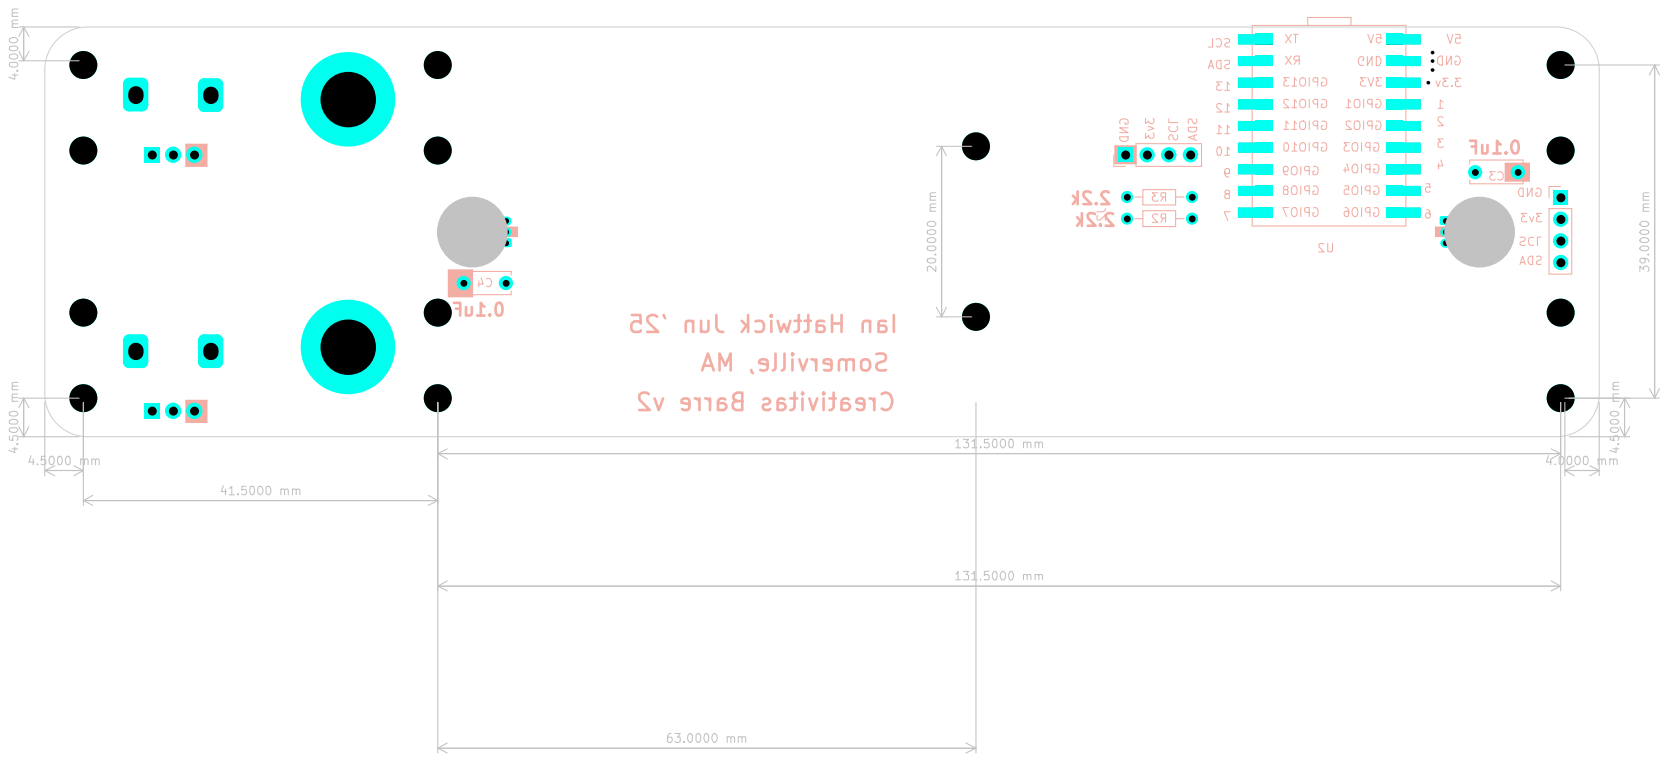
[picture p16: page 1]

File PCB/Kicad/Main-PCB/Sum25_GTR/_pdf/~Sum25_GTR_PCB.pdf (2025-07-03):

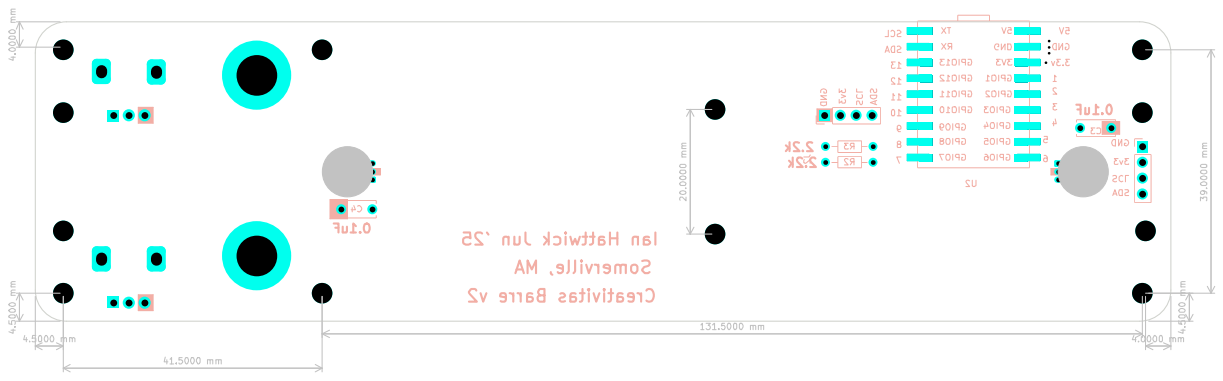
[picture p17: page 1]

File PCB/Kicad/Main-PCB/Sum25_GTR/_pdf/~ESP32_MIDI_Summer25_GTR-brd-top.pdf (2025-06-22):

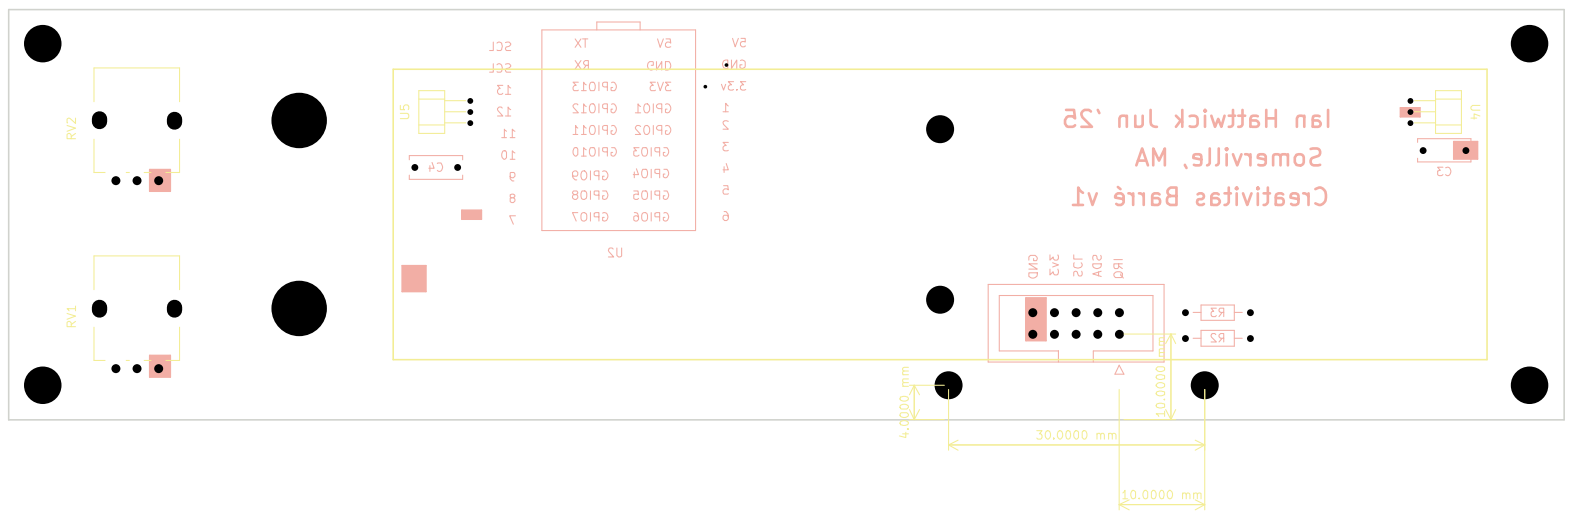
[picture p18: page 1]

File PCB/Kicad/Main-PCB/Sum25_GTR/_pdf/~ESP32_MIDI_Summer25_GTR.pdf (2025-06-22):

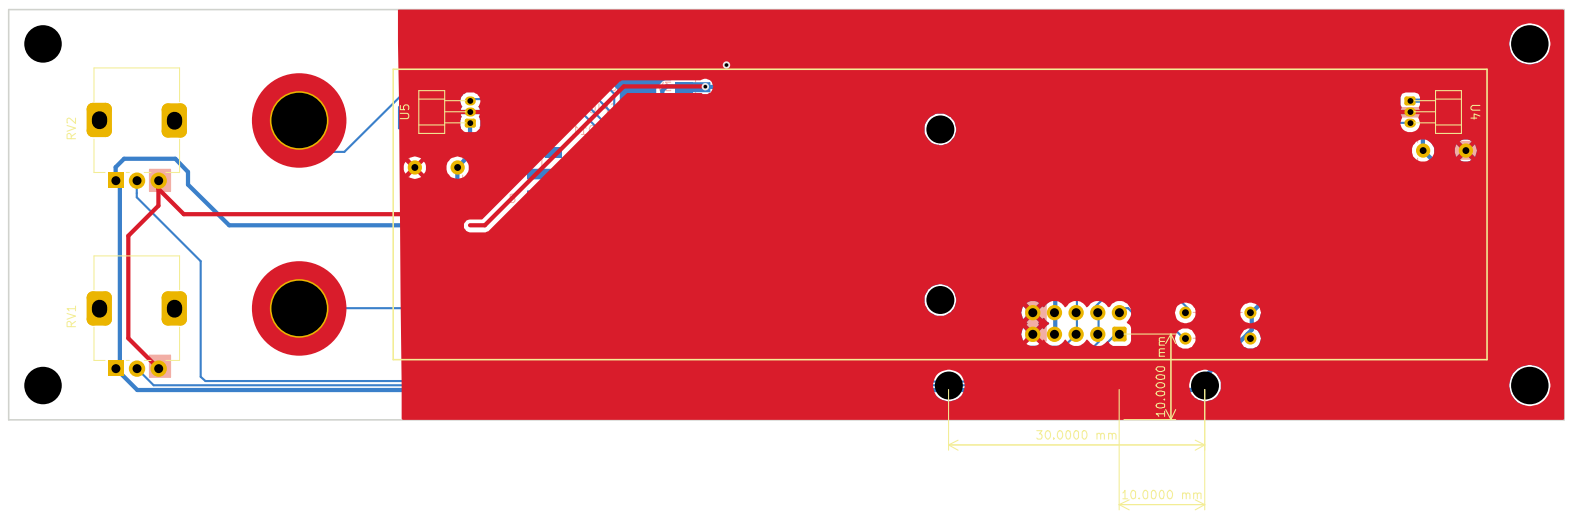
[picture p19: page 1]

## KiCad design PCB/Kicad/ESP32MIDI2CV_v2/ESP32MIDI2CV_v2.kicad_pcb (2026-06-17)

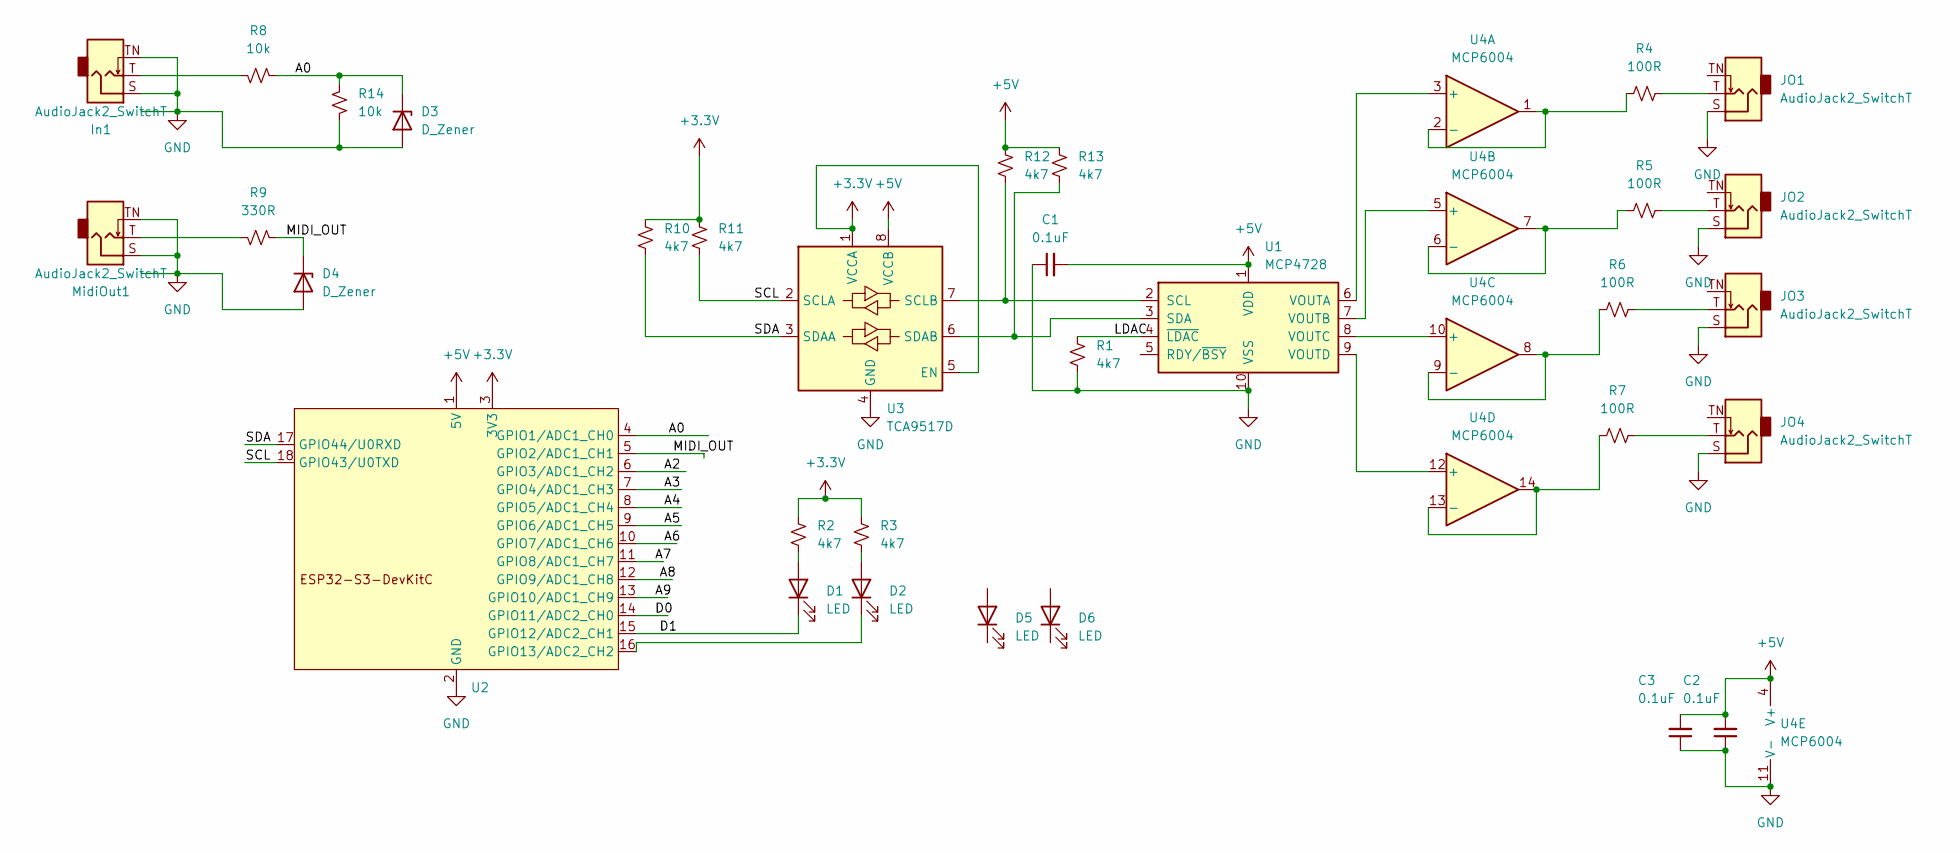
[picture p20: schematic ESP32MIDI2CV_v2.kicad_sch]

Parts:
C1, C2, C3: 0.1uF; C_0805_2012Metric_Pad1.18x1.45mm_HandSolder
D1, D2, D5, D6: LED; LED_D3.0mm
D3, D4: D_Zener; D_DO-35_SOD27_P7.62mm_Horizontal
In1: AudioJack2_SwitchT; Jack_3.5mm_QingPu_WQP-PJ398SM_Vertical_CircularHoles
JO1, JO2, JO3, JO4: AudioJack2_SwitchT; Jack_3.5mm_QingPu_WQP-PJ398SM_Vertical_CircularHoles
MidiOut1: AudioJack2_SwitchT; Jack_3.5mm_QingPu_WQP-PJ398SM_Vertical_CircularHoles
R1, R2, R3, R10, R11, R12, R13: 4k7; R_0805_2012Metric
R4, R5, R6, R7: 100R; R_0805_2012Metric
R8, R14: 10k; R_0805_2012Metric
R9: 330R; R_0805_2012Metric
U1: MCP4728; MSOP-10_3x3mm_P0.5mm
U2: Wifiduino-ESP32S3-SMD
U3: TCA9517D; SOIC-8_3.9x4.9mm_P1.27mm
U4: MCP6004; SO-14_3.9x8.65mm_P1.27mm

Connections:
+3.3V: R2.1, R3.1, R10.1, R11.1, U2.3 (3V3), U3.1 (VCCA), U3.5 (EN)
+5V: C1.2, C2.2, C3.2, R12.1, R13.1, U1.1 (VDD), U2.1 (5V), U3.8 (VCCB), U4.4 (V+)
/A0: D3.1 (K), R8.1, R14.1, U2.4 (GPIO1/ADC1_CH0)
/A2: U2.6 (GPIO3/ADC1_CH2)
/A3: U2.7 (GPIO4/ADC1_CH3)
/A4: U2.8 (GPIO5/ADC1_CH4)
/A5: U2.9 (GPIO6/ADC1_CH5)
/A6: U2.10 (GPIO7/ADC1_CH6)
/A7: U2.11 (GPIO8/ADC1_CH7)
/A8: U2.12 (GPIO9/ADC1_CH8)
/A9: U2.13 (GPIO10/ADC1_CH9)
/D0: U2.14 (GPIO11/ADC2_CH0)
/D1: D1.1 (K), U2.15 (GPIO12/ADC2_CH1)
/LDAC: R1.1, U1.4 (~LDAC)
/MIDI_OUT: D4.1 (K), R9.1, U2.5 (GPIO2/ADC1_CH1)
/SCL: R11.2, U2.18 (GPIO43/U0TXD), U3.2 (SCLA)
/SDA: R10.2, U2.17 (GPIO44/U0RXD), U3.3 (SDAA)
GND: C1.1, C2.1, C3.1, D3.2 (A), D4.2 (A), In1.S, In1.TN, JO1.S, JO2.S, JO3.S, JO4.S, MidiOut1.S, MidiOut1.TN, R1.2, R14.2, U1.10 (VSS), U2.2 (GND), U3.4 (GND), U4.11 (V-)
unnamed: D1.2 (A), R2.2
unnamed: D2.2 (A), R3.2
unnamed: D2.1 (K), U2.16 (GPIO13/ADC2_CH2)
unnamed: In1.T, R8.2
unnamed: JO1.T, R4.2
unnamed: JO2.T, R5.2
unnamed: JO3.T, R6.2
unnamed: JO4.T, R7.2
unnamed: MidiOut1.T, R9.2
unnamed: R12.2, U1.2 (SCL), U3.7 (SCLB)
unnamed: R13.2, U1.3 (SDA), U3.6 (SDAB)
unnamed: U1.6 (VOUTA), U4.3 (+)
unnamed: U1.7 (VOUTB), U4.5 (+)
unnamed: U1.8 (VOUTC), U4.10 (+)
unnamed: U1.9 (VOUTD), U4.12 (+)
unnamed: R4.1, U4.1, U4.2 (-)
unnamed: R5.1, U4.6 (-), U4.7
unnamed: R6.1, U4.8, U4.9 (-)
unnamed: R7.1, U4.13 (-), U4.14

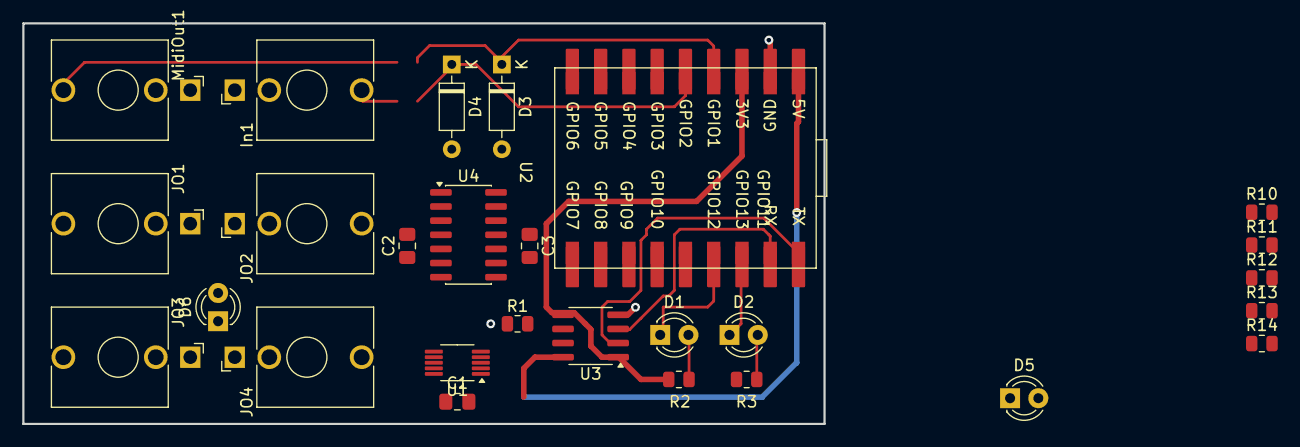
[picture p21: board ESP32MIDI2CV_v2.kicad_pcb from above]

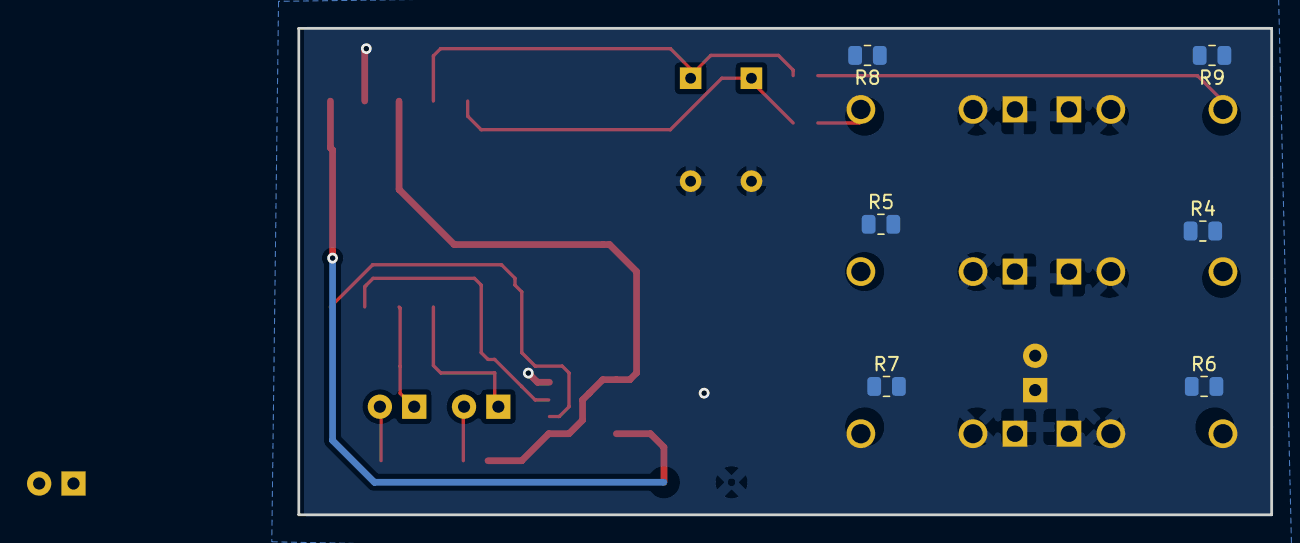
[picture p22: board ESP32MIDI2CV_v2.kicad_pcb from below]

Board: 2 copper layers, 72.0 x 36.0 mm, 33 parts (6 on the bottom side), 28 nets.

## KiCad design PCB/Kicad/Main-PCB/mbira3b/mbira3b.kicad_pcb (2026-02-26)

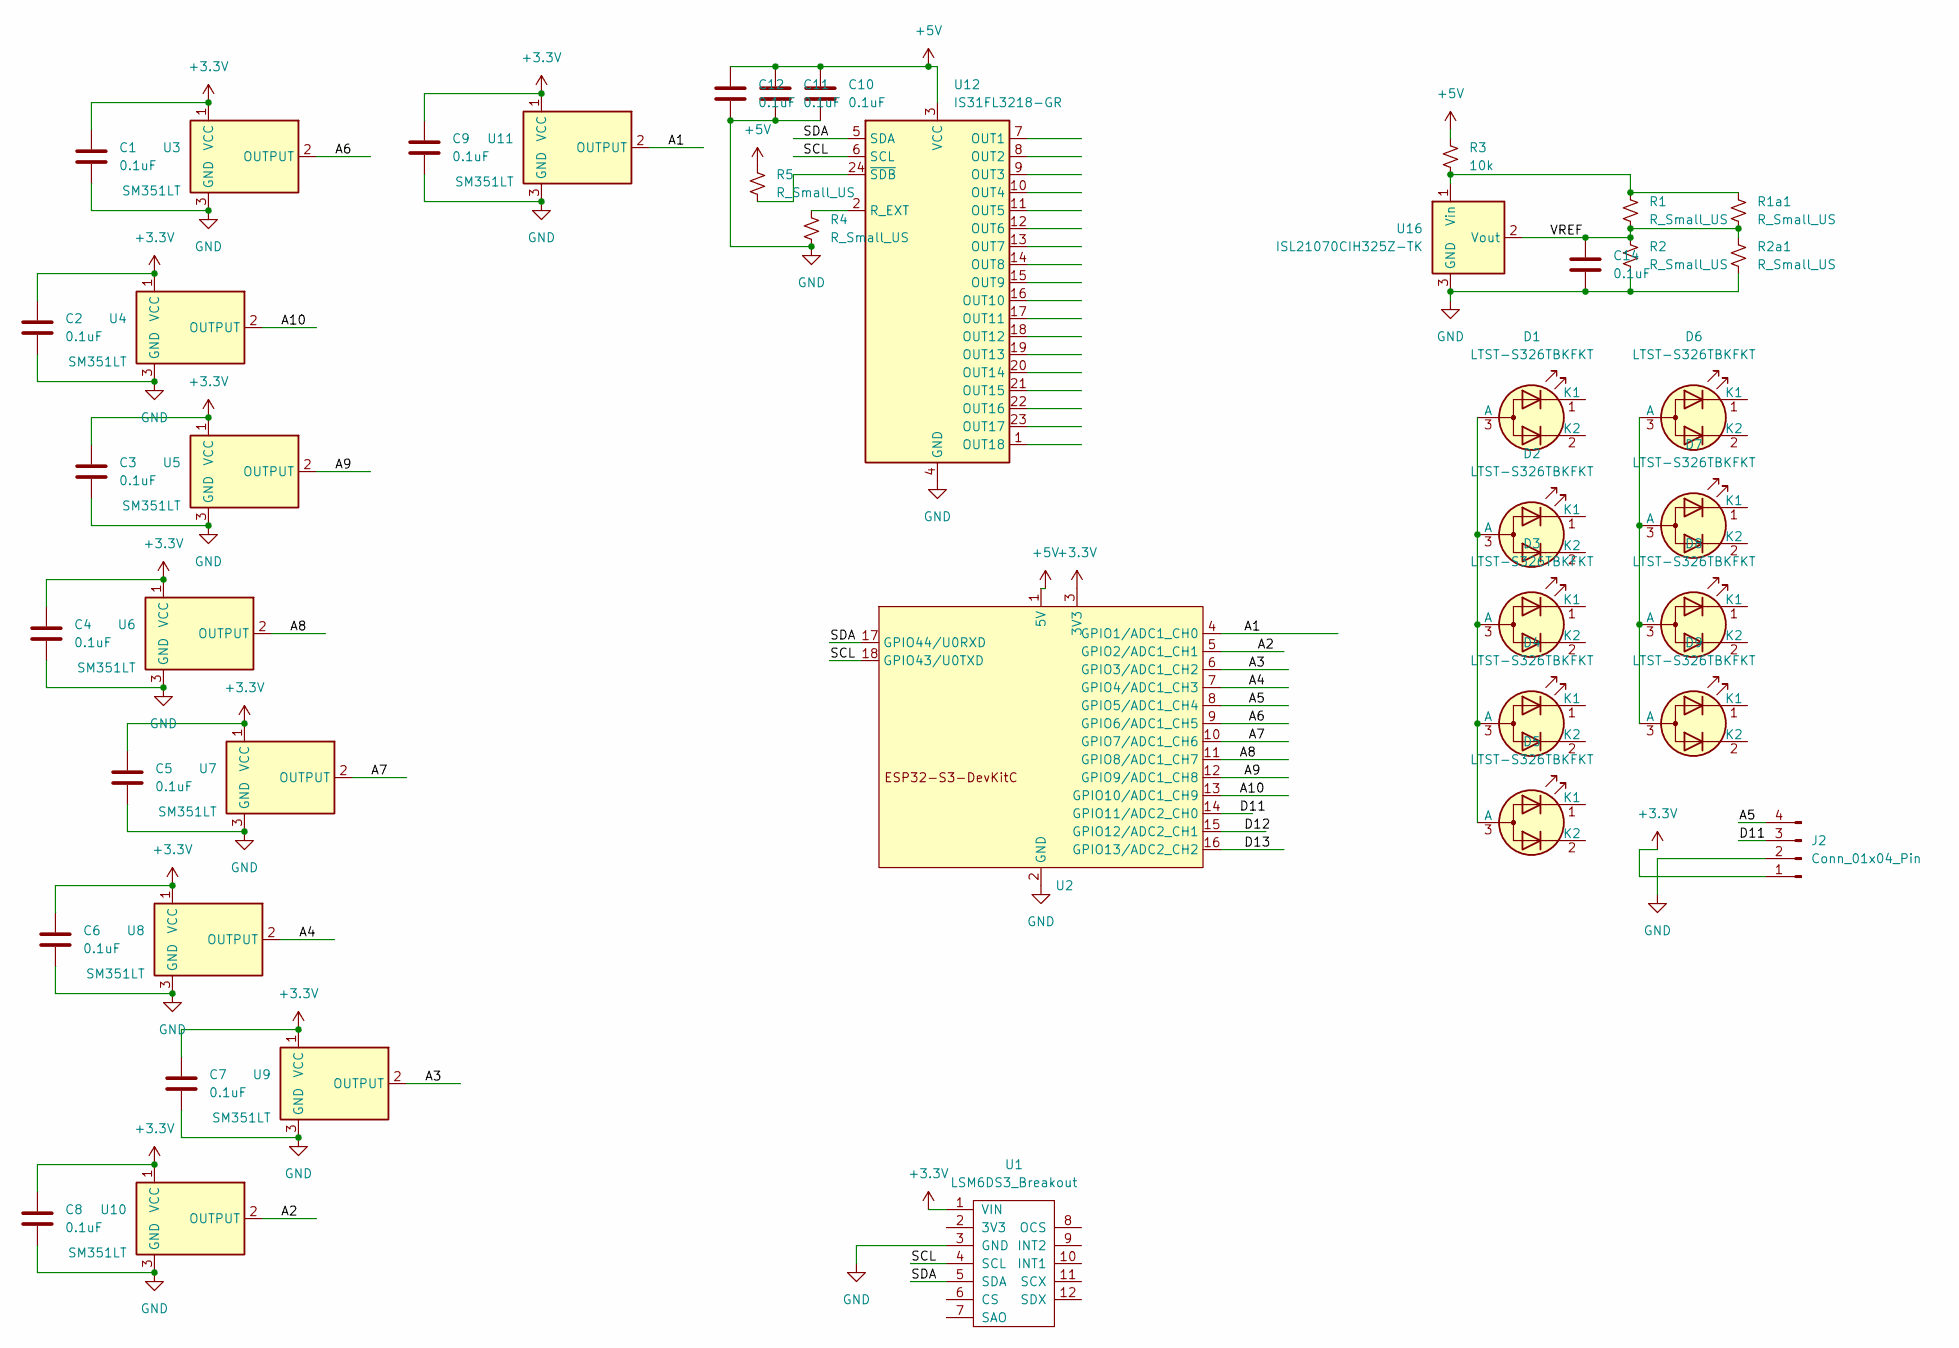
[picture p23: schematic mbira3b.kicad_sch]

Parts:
C1, C2, C3, C4, C5, C6, C7, C8, C9, C10, C11, C12, C14: 0.1uF; C_0805_2012Metric_Pad1.18x1.45mm_HandSolder
D1, D2, D3, D4, D5, D6, D7, D8, D9: LTST-S326TBKFKT; LED_LiteOn_LTST-S326
J2: Conn_01x04_Pin; PinHeader_1x04_P1.27mm_Vertical
R1, R2, R4, R5: R_Small_US; R_0805_2012Metric
R1a1, R2a1: R_Small_US; R_Axial_DIN0207_L6.3mm_D2.5mm_P2.54mm_Vertical
R3: 10k; R_0805_2012Metric
U1: LSM6DS3_Breakout; LSM6DS3_Breakout_oneSide
U2: Wifiduino-ESP32S3-SMD
U3, U4, U5, U6, U7, U8, U9, U10, U11: SM351LT; SOT-23
U12: IS31FL3218-GR; SOP-24_7.5x15.4mm_P1.27mm
U16: ISL21070CIH325Z-TK; SOT-23

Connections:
+3.3V: C1.1, C2.1, C3.1, C4.1, C5.1, C6.1, C7.1, C8.1, C9.1, J2.1, U1.1 (VIN), U2.3 (3V3), U3.1 (VCC), U4.1 (VCC), U5.1 (VCC), U6.1 (VCC), U7.1 (VCC), U8.1 (VCC), U9.1 (VCC), U10.1 (VCC), U11.1 (VCC)
+5V: C10.1, C11.1, C12.1, R3.1, R5.1, U2.1 (5V), U12.3 (VCC)
/A1: U2.4 (GPIO1/ADC1_CH0), U11.2 (OUTPUT)
/A2: U2.5 (GPIO2/ADC1_CH1), U10.2 (OUTPUT)
/A3: U2.6 (GPIO3/ADC1_CH2), U9.2 (OUTPUT)
/A4: U2.7 (GPIO4/ADC1_CH3), U8.2 (OUTPUT)
/A5: J2.4, U2.8 (GPIO5/ADC1_CH4)
/A6: U2.9 (GPIO6/ADC1_CH5), U3.2 (OUTPUT)
/A7: U2.10 (GPIO7/ADC1_CH6), U7.2 (OUTPUT)
/A8: U2.11 (GPIO8/ADC1_CH7), U6.2 (OUTPUT)
/A9: U2.12 (GPIO9/ADC1_CH8), U5.2 (OUTPUT)
/A10: U2.13 (GPIO10/ADC1_CH9), U4.2 (OUTPUT)
/D11: J2.3, U2.14 (GPIO11/ADC2_CH0)
/D12: U2.15 (GPIO12/ADC2_CH1)
/D13: U2.16 (GPIO13/ADC2_CH2)
/SCL: U1.4 (SCL), U2.18 (GPIO43/U0TXD), U12.6 (SCL)
/SDA: U1.5 (SDA), U2.17 (GPIO44/U0RXD), U12.5 (SDA)
/VREF: C14.1, R1.2, R1a1.2, R2.1, R2a1.1, U16.2 (Vout)
GND: C1.2, C2.2, C3.2, C4.2, C5.2, C6.2, C7.2, C8.2, C9.2, C10.2, C11.2, C12.2, C14.2, J2.2, R2.2, R2a1.2, R4.2, U1.3 (GND), U2.2 (GND), U3.3 (GND), U4.3 (GND), U5.3 (GND), U6.3 (GND), U7.3 (GND), U8.3 (GND), U9.3 (GND), U10.3 (GND), U11.3 (GND), U12.4 (GND), U16.3 (GND)
unnamed: D1.3 (A), D2.3 (A), D3.3 (A), D4.3 (A), D5.3 (A)
unnamed: D6.3 (A), D7.3 (A), D8.3 (A), D9.3 (A)
unnamed: R4.1, U12.2 (R_EXT)
unnamed: R5.2, U12.24 (~SDB)
unnamed: R1.1, R1a1.1, R3.2, U16.1 (Vin)

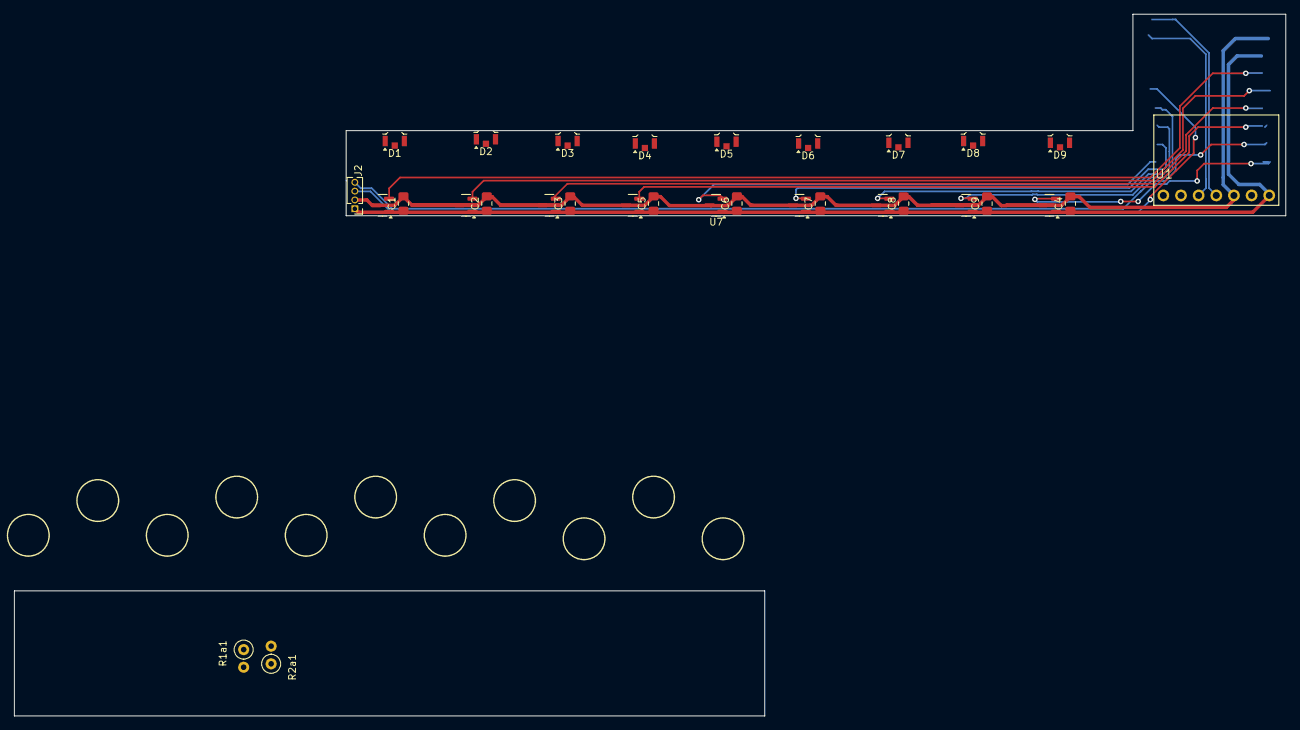
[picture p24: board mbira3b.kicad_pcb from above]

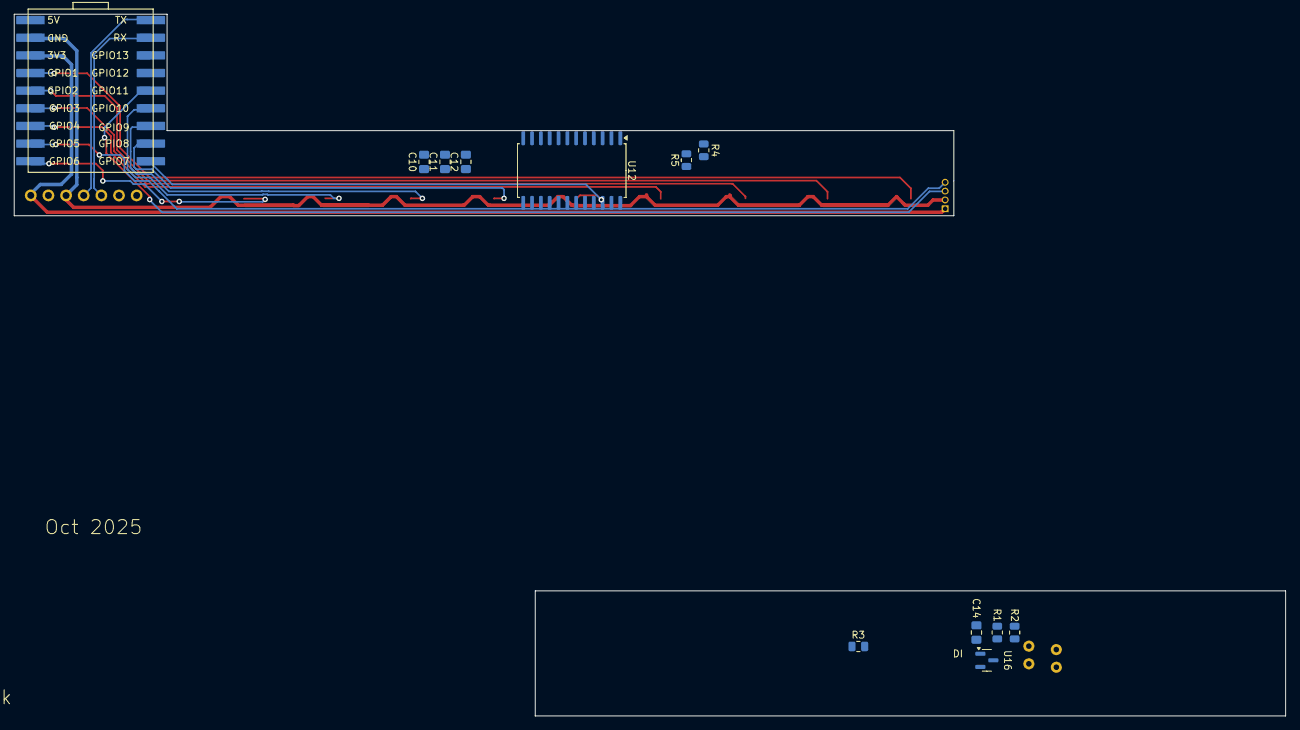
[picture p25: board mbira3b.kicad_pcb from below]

Board: 2 copper layers, 135.2 x 29.0 mm, 43 parts (12 on the bottom side), 22 nets.

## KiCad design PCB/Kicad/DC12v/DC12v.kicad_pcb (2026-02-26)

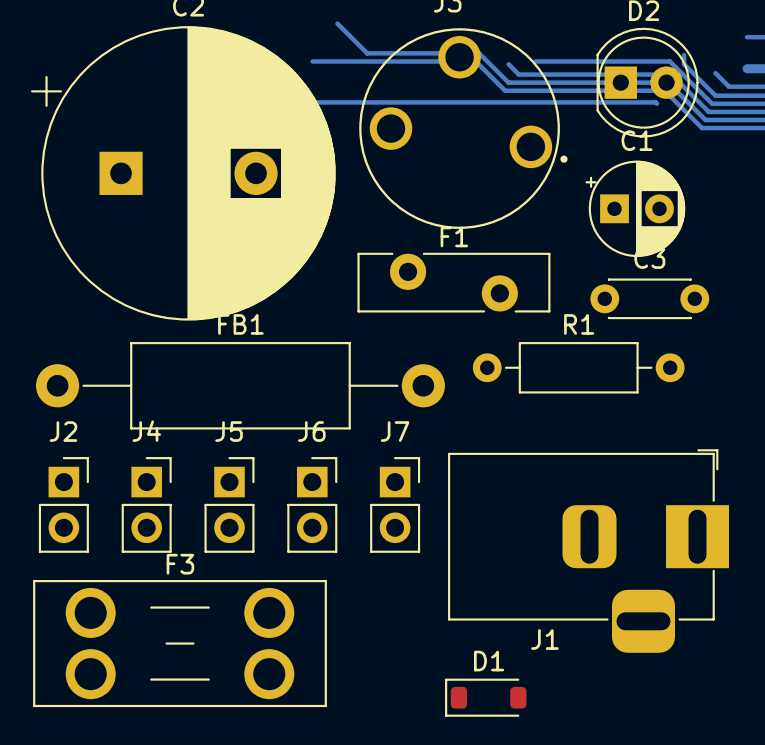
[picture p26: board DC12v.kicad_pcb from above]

Board: 2 copper layers, 16 parts (0 on the bottom side), 5 nets.

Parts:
C1: 1uF; CP_Radial_D5.0mm_P2.50mm
C2: 3300uF; CP_Radial_D16.0mm_P7.50mm
C3: 0.1uF; C_Disc_D4.3mm_W1.9mm_P5.00mm
D1: TPSMF4L15A; D_SOD-123
D2: LED; LED_D5.0mm
F1: MF-R110; Fuse_Bourns_MF-RG500
F3: Fuse; Fuseholder_Blade_Mini_Keystone_3568
FB1: B82144A2473J; R_Axial_DIN0414_L11.9mm_D4.5mm_P20.32mm_Horizontal
J1: Barrel_Jack_Switch; BarrelJack_Horizontal
J2, J4, J5, J6, J7: Conn_01x02_Pin; PinSocket_1x02_P2.54mm_Vertical
J3: Barrel_Jack_Switch; SWITCHCRAFT_PC722A
R1: R_Small_US; R_Axial_DIN0207_L6.3mm_D2.5mm_P10.16mm_Horizontal

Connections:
+12V: C1.1, C2.1, C3.1, F1.1, F3.2, J2.2, J4.2, J5.2, J6.2, J7.2, R1.1
GND: C1.2, C2.2, C3.2, D1.2 (A), D2.1 (K), J1.2, J2.1, J4.1, J5.1, J6.1, J7.1
unnamed: D1.1 (K), F3.1, J1.1
unnamed: D2.2 (A), R1.2
unnamed: F1.2, FB1.1

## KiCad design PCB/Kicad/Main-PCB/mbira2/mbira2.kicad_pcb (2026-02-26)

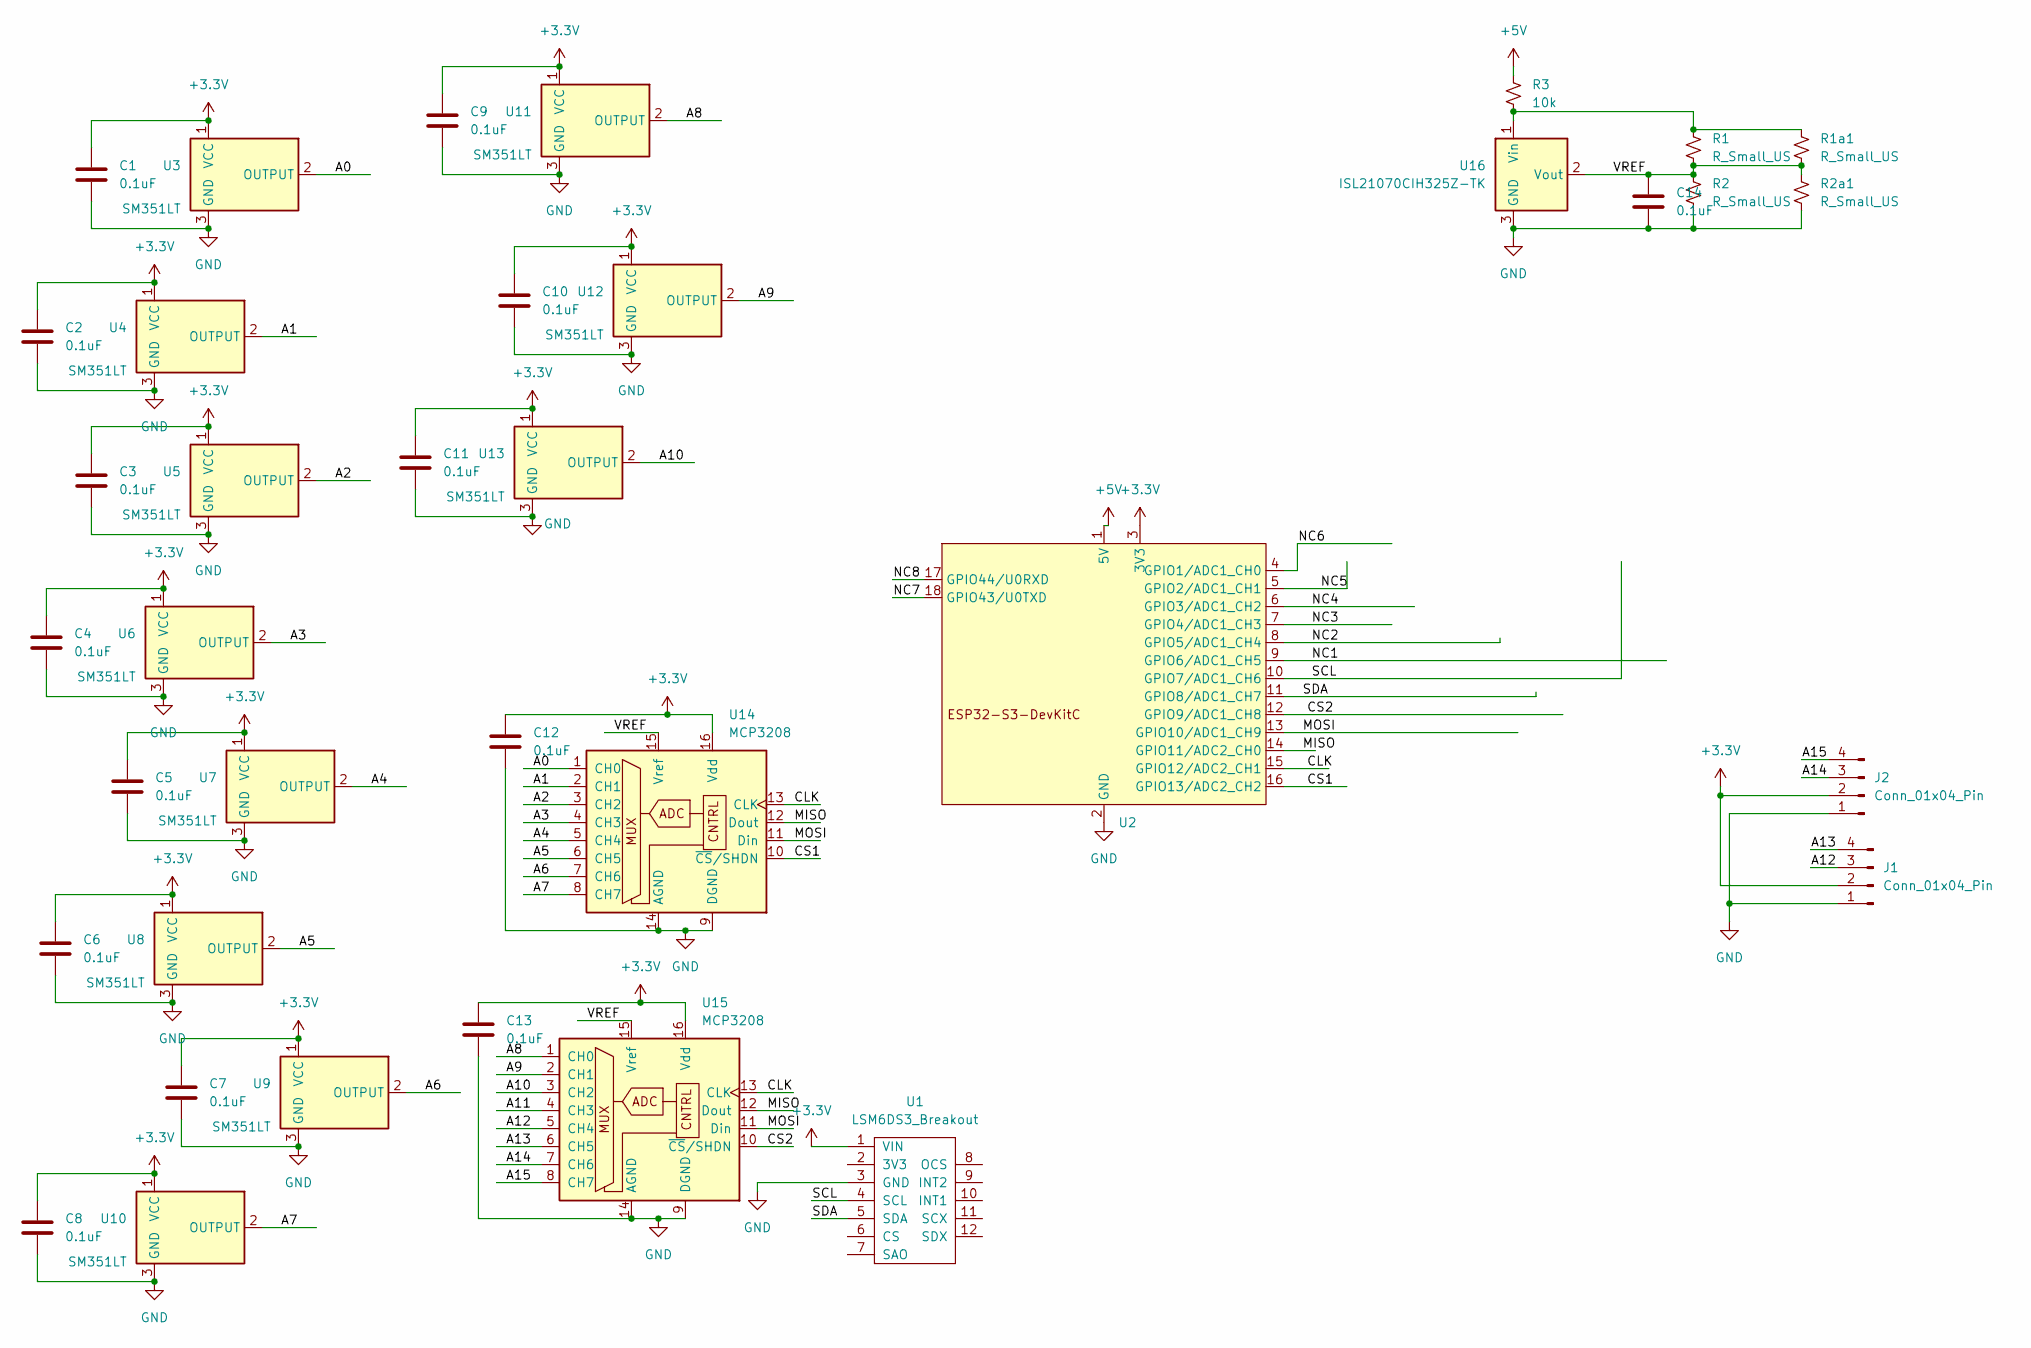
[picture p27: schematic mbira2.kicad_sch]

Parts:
C1, C2, C3, C4, C5, C6, C7, C8, C9, C10, C11, C12, C13, C14: 0.1uF; C_0805_2012Metric_Pad1.18x1.45mm_HandSolder
J1, J2: Conn_01x04_Pin; PinHeader_1x04_P1.27mm_Vertical
R1, R2: R_Small_US; R_0805_2012Metric
R1a1, R2a1: R_Small_US; R_Axial_DIN0207_L6.3mm_D2.5mm_P2.54mm_Vertical
R3: 10k; R_0805_2012Metric
U1: LSM6DS3_Breakout; LSM6DS3_Breakout_oneSide
U2: Wifiduino-ESP32S3-SMD
U3, U4, U5, U6, U7, U8, U9, U10, U11, U12, U13: SM351LT; SOT-23
U14, U15: MCP3208; SOIC-16_3.9x9.9mm_P1.27mm
U16: ISL21070CIH325Z-TK; SOT-23

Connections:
+3.3V: C1.1, C2.1, C3.1, C4.1, C5.1, C6.1, C7.1, C8.1, C9.1, C10.1, C11.1, C12.1, C13.1, J1.2, J2.2, U1.1 (VIN), U2.3 (3V3), U3.1 (VCC), U4.1 (VCC), U5.1 (VCC), U6.1 (VCC), U7.1 (VCC), U8.1 (VCC), U9.1 (VCC), U10.1 (VCC), U11.1 (VCC), U12.1 (VCC), U13.1 (VCC), U14.16 (Vdd), U15.16 (Vdd)
+5V: R3.1, U2.1 (5V)
/A0: U3.2 (OUTPUT), U14.1 (CH0)
/A1: U4.2 (OUTPUT), U14.2 (CH1)
/A2: U5.2 (OUTPUT), U14.3 (CH2)
/A3: U6.2 (OUTPUT), U14.4 (CH3)
/A4: U7.2 (OUTPUT), U14.5 (CH4)
/A5: U8.2 (OUTPUT), U14.6 (CH5)
/A6: U9.2 (OUTPUT), U14.7 (CH6)
/A7: U10.2 (OUTPUT), U14.8 (CH7)
/A8: U11.2 (OUTPUT), U15.1 (CH0)
/A9: U12.2 (OUTPUT), U15.2 (CH1)
/A10: U13.2 (OUTPUT), U15.3 (CH2)
/A11: U15.4 (CH3)
/A12: J1.3, U15.5 (CH4)
/A13: J1.4, U15.6 (CH5)
/A14: J2.3, U15.7 (CH6)
/A15: J2.4, U15.8 (CH7)
/CLK: U2.15 (GPIO12/ADC2_CH1), U14.13 (CLK), U15.13 (CLK)
/CS1: U2.16 (GPIO13/ADC2_CH2), U14.10 (~CS/SHDN)
/CS2: U2.12 (GPIO9/ADC1_CH8), U15.10 (~CS/SHDN)
/MISO: U2.14 (GPIO11/ADC2_CH0), U14.12 (Dout), U15.12 (Dout)
/MOSI: U2.13 (GPIO10/ADC1_CH9), U14.11 (Din), U15.11 (Din)
/NC1: U2.9 (GPIO6/ADC1_CH5)
/NC2: U2.8 (GPIO5/ADC1_CH4)
/NC3: U2.7 (GPIO4/ADC1_CH3)
/NC4: U2.6 (GPIO3/ADC1_CH2)
/NC5: U2.5 (GPIO2/ADC1_CH1)
/NC6: U2.4 (GPIO1/ADC1_CH0)
/NC7: U2.18 (GPIO43/U0TXD)
/NC8: U2.17 (GPIO44/U0RXD)
/SCL: U1.4 (SCL), U2.10 (GPIO7/ADC1_CH6)
/SDA: U1.5 (SDA), U2.11 (GPIO8/ADC1_CH7)
/VREF: C14.1, R1.2, R1a1.2, R2.1, R2a1.1, U14.15 (Vref), U15.15 (Vref), U16.2 (Vout)
GND: C1.2, C2.2, C3.2, C4.2, C5.2, C6.2, C7.2, C8.2, C9.2, C10.2, C11.2, C12.2, C13.2, C14.2, J1.1, J2.1, R2.2, R2a1.2, U1.3 (GND), U2.2 (GND), U3.3 (GND), U4.3 (GND), U5.3 (GND), U6.3 (GND), U7.3 (GND), U8.3 (GND), U9.3 (GND), U10.3 (GND), U11.3 (GND), U12.3 (GND), U13.3 (GND), U14.9 (DGND), U14.14 (AGND), U15.9 (DGND), U15.14 (AGND), U16.3 (GND)
unnamed: R1.1, R1a1.1, R3.2, U16.1 (Vin)

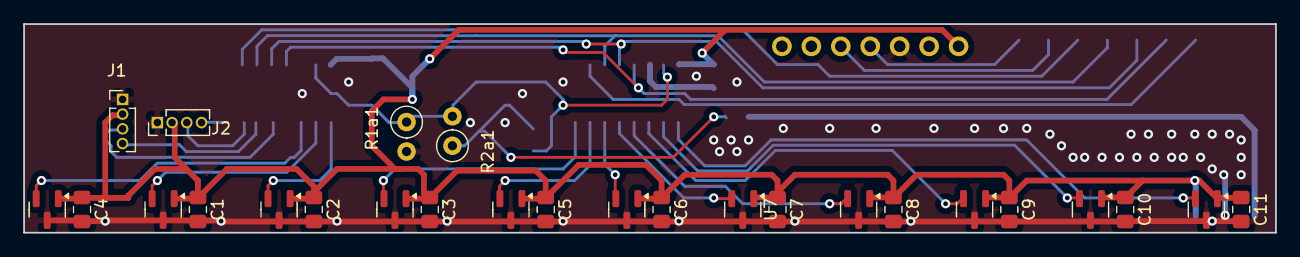
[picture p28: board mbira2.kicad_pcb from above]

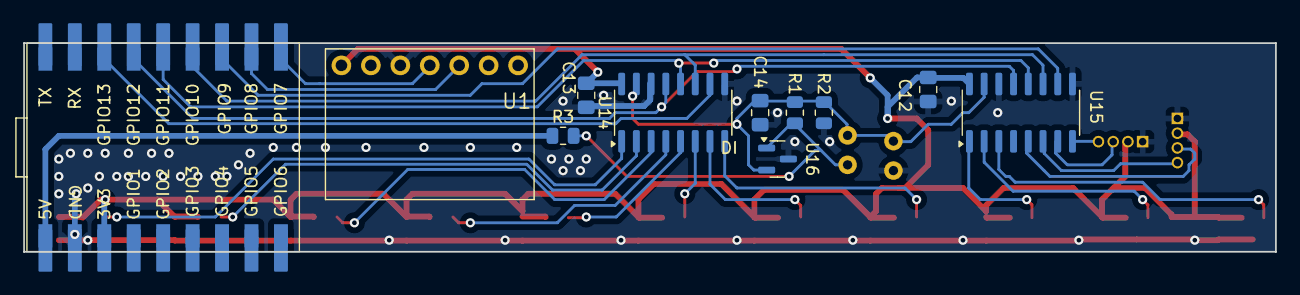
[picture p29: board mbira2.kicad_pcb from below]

Board: 2 copper layers, 108.0 x 18.0 mm, 37 parts (11 on the bottom side), 27 nets.

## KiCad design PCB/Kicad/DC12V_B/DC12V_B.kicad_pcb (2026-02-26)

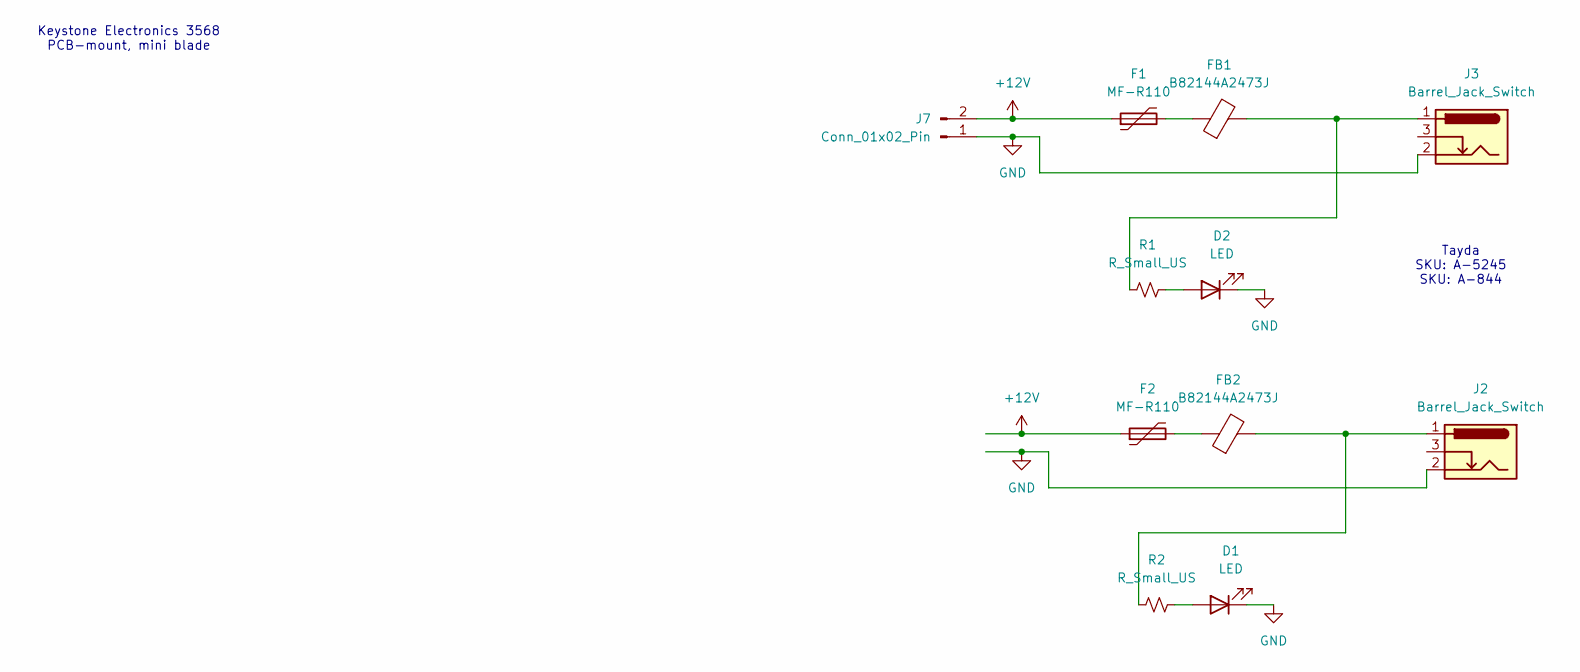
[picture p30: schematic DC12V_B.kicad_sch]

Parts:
D1, D2: LED; LED_D5.0mm
F1, F2: MF-R110; Fuse_Bourns_MF-RG500
FB1, FB2: B82144A2473J; R_Axial_DIN0414_L11.9mm_D4.5mm_P20.32mm_Horizontal
J2, J3: Barrel_Jack_Switch; SWITCHCRAFT_PC722A
J7: Conn_01x02_Pin; PinSocket_1x02_P2.54mm_Vertical
R1, R2: R_Small_US; R_Axial_DIN0207_L6.3mm_D2.5mm_P10.16mm_Horizontal

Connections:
+12V: F1.1, F2.1, J7.2
GND: D1.1 (K), D2.1 (K), J2.2, J3.2, J7.1
unnamed: D1.2 (A), R2.2
unnamed: D2.2 (A), R1.2
unnamed: F1.2, FB1.1
unnamed: F2.2, FB2.1
unnamed: FB1.2, J3.1, R1.1
unnamed: FB2.2, J2.1, R2.1

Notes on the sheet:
Tayda SKU: A-5245 SKU: A-844
Keystone Electronics 3568 PCB-mount, mini blade

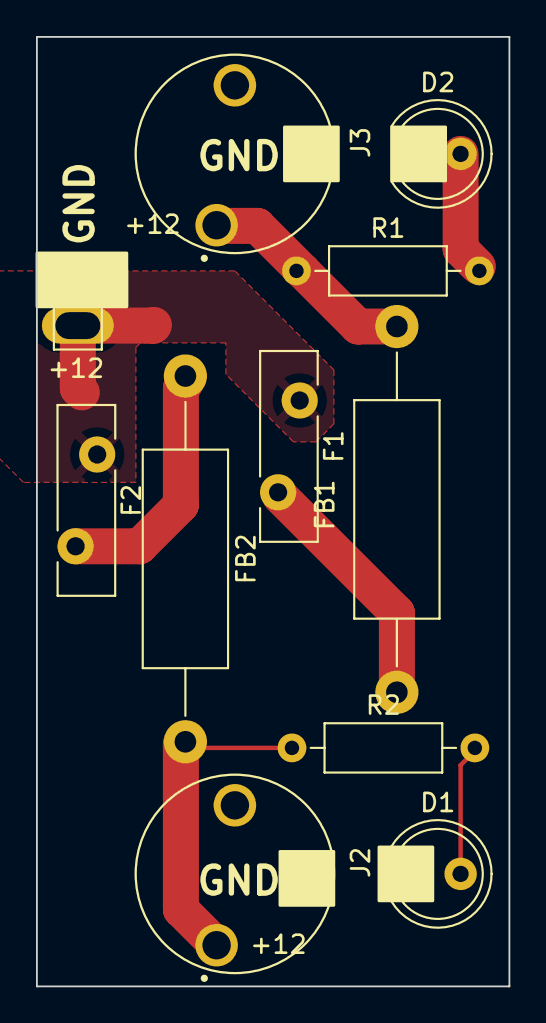
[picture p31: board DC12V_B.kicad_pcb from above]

Board: 2 copper layers, 26.2 x 52.8 mm, 11 parts (0 on the bottom side), 8 nets.

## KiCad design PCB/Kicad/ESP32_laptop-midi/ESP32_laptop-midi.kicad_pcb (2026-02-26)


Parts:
C1, C3, C4, C5: 10nF; C_0805_2012Metric_Pad1.18x1.45mm_HandSolder
C2, C7, C8, C9: 0.1uF; C_0805_2012Metric_Pad1.18x1.45mm_HandSolder
D1, D2, D3, D4: WS2812B; LED_WS2812B_PLCC4_5.0x5.0mm_P3.2mm
H1, H2, H3, H4, H5, H6: MountingHole; MountingHole_3.2mm_M3
SW5, SW6, SW7, SW8: SW_SPST; SW_Cherry_MX_1.00u_PCB
SW9, SW10: RotaryEncoder; EC10E1220505_AAL
U2: Wifiduino-ESP32S3-SMD

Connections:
+3.3V: C2.2, C7.2, C8.2, C9.2, D1.1 (VDD), D2.1 (VDD), D3.1 (VDD), D4.1 (VDD), U2.3 (3V3)
+5V: U2.1 (5V)
/A0: SW5.2 (B), U2.4 (GPIO1/ADC1_CH0)
/A1: SW8.2 (B), U2.5 (GPIO2/ADC1_CH1)
/A2: SW6.2 (B), U2.6 (GPIO3/ADC1_CH2)
/A3: SW7.2 (B), U2.7 (GPIO4/ADC1_CH3)
/A8: U2.12 (GPIO9/ADC1_CH8)
/A9: U2.13 (GPIO10/ADC1_CH9)
/D0: U2.14 (GPIO11/ADC2_CH0)
/DI: D1.4 (DIN), U2.17 (GPIO44/U0RXD)
/EncA1: C3.2, SW9.A, U2.8 (GPIO5/ADC1_CH4)
/EncA2: C5.2, SW10.A, U2.10 (GPIO7/ADC1_CH6)
/EncB1: C1.1, SW9.B, U2.9 (GPIO6/ADC1_CH5)
/EncB2: C4.1, SW10.B, U2.11 (GPIO8/ADC1_CH7)
GND: C1.2, C2.1, C3.1, C4.2, C5.1, C7.1, C8.1, C9.1, D1.3 (VSS), D2.3 (VSS), D3.3 (VSS), D4.3 (VSS), SW5.1 (A), SW6.1 (A), SW7.1 (A), SW8.1 (A), SW9.C, SW10.C, U2.2 (GND)
unnamed: D1.2 (DOUT), D2.4 (DIN)
unnamed: D2.2 (DOUT), D3.4 (DIN)
unnamed: D3.2 (DOUT), D4.4 (DIN)


Board: 2 copper layers, 97.0 x 38.0 mm, 25 parts (1 on the bottom side), 14 nets.

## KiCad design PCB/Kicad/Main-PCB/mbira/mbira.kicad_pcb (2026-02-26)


Board: 2 copper layers, 108.0 x 50.0 mm, 42 parts (0 on the bottom side), 18 nets, no tracks yet.

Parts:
C1, C2, C3, C4, C5, C6, C7, C8, C9, C10, C11: 0.1uF; C_0805_2012Metric_Pad1.18x1.45mm_HandSolder
D1, D2: WS2812B; LED_D5.0mm-4_RGB_Wide_Pins
H1, H2, H13, H14, H15, H16, H18: MountingHole; MountingHole_4.5mm
H5, H6: MountingHole; MountingHole_3.2mm_M3_ISO14580
RV1, RV2: R_Potentiometer_Dual; potentiometer_wheel_10mm_SMD-shield
SW1, SW2, SW3, SW4: SW_DPST; SW_Push_1P1T_NO_CK_KSC6xxJ
U1: LSM6DS3_Breakout; LSM6DS3_Breakout_oneSide
U2: Wifiduino-ESP32S3-SMD
U3, U4, U5, U6, U7, U8, U9, U10, U11, U12, U13: SM351LT; SOT-23
U14: MCP3208; SOIC-16_3.9x9.9mm_P1.27mm

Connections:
+3.3V: C1.1, C2.1, C3.1, C4.1, C5.1, C6.1, C7.1, C8.1, C9.1, C10.1, C11.1, D1.3 (VDD), D2.3 (VDD), RV1.1 (1A), RV2.1 (1A), U1.1 (VIN), U2.3 (3V3), U3.1 (VCC), U4.1 (VCC), U5.1 (VCC), U6.1 (VCC), U7.1 (VCC), U8.1 (VCC), U9.1 (VCC), U10.1 (VCC), U11.1 (VCC), U12.1 (VCC), U13.1 (VCC)
/A0: U2.4 (GPIO1/ADC1_CH0), U3.2 (OUTPUT)
/A1: U2.5 (GPIO2/ADC1_CH1), U4.2 (OUTPUT)
/A2: U2.6 (GPIO3/ADC1_CH2), U5.2 (OUTPUT)
/A3: U2.7 (GPIO4/ADC1_CH3), U6.2 (OUTPUT)
/A4: U2.8 (GPIO5/ADC1_CH4), U7.2 (OUTPUT)
/A5: U2.9 (GPIO6/ADC1_CH5), U8.2 (OUTPUT)
/A6: U2.10 (GPIO7/ADC1_CH6), U9.2 (OUTPUT)
/A7: U2.11 (GPIO8/ADC1_CH7), U10.2 (OUTPUT)
/A8: U2.12 (GPIO9/ADC1_CH8), U11.2 (OUTPUT)
/A9: U2.13 (GPIO10/ADC1_CH9), U12.2 (OUTPUT)
/A10: U2.16 (GPIO13/ADC2_CH2), U13.2 (OUTPUT)
/A11: RV1.6 (Shield), RV2.6 (Shield), U2.15 (GPIO12/ADC2_CH1)
/D0: D1.4 (DIN), U2.14 (GPIO11/ADC2_CH0)
/SCL: U1.4 (SCL), U2.18 (GPIO43/U0TXD)
/SDA: U1.5 (SDA), U2.17 (GPIO44/U0RXD)
GND: C1.2, C2.2, C3.2, C4.2, C5.2, C6.2, C7.2, C8.2, C9.2, C10.2, C11.2, D1.2 (VSS), D2.2 (VSS), RV1.5 (Common), RV2.5 (Common), U1.3 (GND), U2.2 (GND), U3.3 (GND), U4.3 (GND), U5.3 (GND), U6.3 (GND), U7.3 (GND), U8.3 (GND), U9.3 (GND), U10.3 (GND), U11.3 (GND), U12.3 (GND), U13.3 (GND)
unnamed: D1.1 (DOUT), D2.4 (DIN)

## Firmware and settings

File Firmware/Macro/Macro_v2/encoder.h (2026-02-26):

// based on https://github.com/igorantolic/ai-esp32-rotary-encoder
// which was itself based on https://github.com/marcmerlin/IoTuz code - extracted and modified Encoder code
// 
// 

// Rotary Encocer
#define DEFAULT_A_PIN 25
#define DEFAULT_B_PIN 26
#define DEFAULT_BUT_PIN 15
#define DEFAULT_DIVIDER 1

typedef enum {
	BUT_DOWN = 0,
	BUT_PUSHED = 1,
	BUT_UP = 2,
	BUT_RELEASED = 3,
} ButtonState;

class Esp32Encoder {
	
private:
	portMUX_TYPE mux = portMUX_INITIALIZER_UNLOCKED;
	volatile int16_t encoder0Pos = 0;
	bool _circleValues = false;
	bool isEnabled = true;
  uint32_t _count;
  long _raw;

	uint8_t encoderAPin      = DEFAULT_A_PIN;
	uint8_t encoderBPin      = DEFAULT_B_PIN;
	uint8_t encoderButtonPin = DEFAULT_BUT_PIN;

	volatile uint8_t old_AB;
	int16_t lastReadEncoder0Pos;
  uint8_t divider;
	bool previous_butt_state;
	uint16_t button_history = 0;
	uint16_t onPattern = 1<<15;
	uint16_t offPattern = 1;

	int8_t enc_states[16] = {0,-1,1,0,1,0,0,-1,-1,0,0,1,0,1,-1,0};
	void(*ISR_callback)();
	volatile byte ISRflag = 0;

public: 
	Esp32Encoder(
		uint8_t encoderAPin = DEFAULT_A_PIN,
		uint8_t encoderBPin = DEFAULT_B_PIN,
		uint8_t encoderButtonPin = DEFAULT_BUT_PIN,
    uint8_t divider = DEFAULT_DIVIDER,
    uint8_t _num = 50
	);
	void IRAM_ATTR readEncoder_ISR();
	
	void begin(void (*ISR_callback)(void));
	byte available();
	int16_t readEncoder();
  int16_t delta();
  int32_t count();
	int16_t encoderChanged();
  byte ccNumber = 0;
	ButtonState button();

};

// based on https://github.com/igorantolic/ai-esp32-rotary-encoder
// which was itself based on https://github.com/marcmerlin/IoTuz code - extracted and modified Encoder code
// 
// 


void IRAM_ATTR Esp32Encoder::readEncoder_ISR()
{	
	portENTER_CRITICAL_ISR(&(this->mux));
  this->ISRflag = 1;
	this->old_AB <<= 2;                   //remember previous state
  this->old_AB;
	int8_t ENC_PORT = (
	  (digitalRead(this->encoderBPin)) ? (1 << 1) : 0) + 
	  ((digitalRead(this->encoderAPin)) ? (1 << 0) : 0
	  );
	this->old_AB |= ( ENC_PORT & 0x03 );  //add current state
	this->encoder0Pos += ( this->enc_states[( this->old_AB & 0x0f )]);		
	portEXIT_CRITICAL_ISR(&(this->mux));
}//readEncoder_ISR

Esp32Encoder::Esp32Encoder(uint8_t _APin, uint8_t _BPin, uint8_t _ButtonPin, uint8_t _divider, uint8_t _num)
{
	this->old_AB = 0;
	
	this->encoderAPin = _APin;
	this->encoderBPin = _BPin;
	this->encoderButtonPin = _ButtonPin;
  this->divider = _divider;
  this->ccNumber = _num;
	pinMode(this->encoderAPin, INPUT_PULLUP);
	pinMode(this->encoderBPin, INPUT_PULLUP);

}//Esp32Encoder

//Esp32Encoder::Esp32Encoder(uint8_t _APin, uint8_t _BPin, uint8_t _ButtonPin, uint8_t _divider)
//{
//  this->old_AB = 0;
//  
//  this->encoderAPin = _APin;
//  this->encoderBPin = _BPin;
//  this->encoderButtonPin = _ButtonPin;
//  this->divider =_divider;
//  pinMode(this->encoderAPin, INPUT);
//  pinMode(this->encoderBPin, INPUT);
//
//}//Esp32Encoder


int16_t Esp32Encoder::readEncoder() {
  int32_t out = 0;  // default when not enough ticks yet
  portENTER_CRITICAL(&mux);

  if (divider <= 0) divider = 1;  // safety
  int32_t pos = encoder0Pos;

  // Only report when we've crossed a full 'divider' step (in either direction)
  if (pos >= divider || pos <= -divider) {
    out = pos / divider;                            // number of steps to report
    encoder0Pos = pos - out * divider;              // keep leftover ticks
    ISRflag = 0;                                    // if you actually use this
  }

  portEXIT_CRITICAL(&mux);
  return static_cast<int16_t>(out);
}

int16_t Esp32Encoder::delta() {   return (readEncoder()); }

int32_t Esp32Encoder::count()
{
  int encoderDelta = readEncoder();
  if (encoderDelta == 0) return this->_count ;
  int prevRaw = this->_raw;
  this->_raw+=encoderDelta;
  if(  abs(this->_raw) > this->divider-1 || (abs(this->_raw)-abs(prevRaw)<0)){
    this->_raw=0;
    encoderDelta > 0 ? this->_count++ : this->_count--;
  }
  return (this->_count);
}

int16_t Esp32Encoder::encoderChanged() 
{
	int16_t _encoder0Pos = readEncoder();
	
	int16_t encoder0Diff = _encoder0Pos - this->lastReadEncoder0Pos;

	this->lastReadEncoder0Pos = _encoder0Pos;
	return encoder0Diff;
}//readEncoder

void Esp32Encoder::begin(void (*ISR_callback)(void))
{
	this->previous_butt_state = 0;
	pinMode(this->encoderButtonPin, INPUT_PULLUP);
  pinMode(this->encoderAPin, INPUT_PULLUP);
  pinMode(this->encoderBPin, INPUT_PULLUP);

  attachInterrupt(digitalPinToInterrupt(encoderAPin), ISR_callback, CHANGE);
  attachInterrupt(digitalPinToInterrupt(encoderBPin), ISR_callback, CHANGE);

  Serial.println(encoderAPin);
  Serial.println(encoderBPin);
}//begin

byte Esp32Encoder::available(){
  return ISRflag;
}

ButtonState Esp32Encoder::button()
{
	uint8_t butt_state = 255;
  byte curReading = digitalRead(this->encoderButtonPin);
  this->button_history = (this->button_history<<1) + curReading;
  if(this->button_history == this->onPattern ) butt_state = 1;
  else if (this->button_history == this->offPattern ) butt_state = 0;

  if( butt_state  <=1  ){
    previous_butt_state = butt_state;
     switch(butt_state){
      case 1: return  BUT_PUSHED;
      case 0: return BUT_RELEASED;
     }
  }else {
    switch(previous_butt_state){
      case 0: return  BUT_DOWN;
      case 1: return BUT_UP;
     }
  }
}//button

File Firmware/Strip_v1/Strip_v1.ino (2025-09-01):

/*
  File Name: ESP32_MIDI.ino
  Version: v6
  Creator: Ian Hattwick
  Date: Jan 19, 2025

  Note: this is an exploatory version trying to switch to USBMIDI.h
  - tested as working!

  Description:
  This program allows an ESP32_S3 to act as a class compliant midi device.
  NOTE: the ESP32 USB Mode MUST be set to "USB OTG (TinyUSB)".
  - once this is done, the board will no longer be recongized by Arduino
  - in order to reprogram the board, you will need to hold down the buttons on the board
  - hold down the B (boot) button and tap the R (reset) button
  - Arduino should recognize the ESP32s3
  - USB CDC on boot may need to be set to 'disabled'
  
  Input Signals:
  - capacitive touch pads. 8 for fingers, two alt pads, 
  - two potentiometers
  
  Output Signals:
  - two external LED outputs, on pin 43
  - onboard LED on pin 21
  - MIDI out via USB

  Version notes:
  - this version adds cc control for pots and bar

  Additional Information:
  - Supports serial debugging. set SERIAL_DEBUG to 1 to enable debugging
  - ENABLE_USB_MIDI should be set to 1 to enable USB MIDI functionality.
*/
const byte ENABLE_USB_MIDI = 1;
const byte SERIAL_DEBUG = 0;

//sensor global variables
byte ccSendRate = 1;
int touchChargeTime = 20;
int touchSleepTime = 100;

#include "USB_MIDI.h"
#include <Wire.h>
#include "potentiometer.h"
#include "controller.h"
//#include "./src/LSM6.h"
#include "./src/BMI160Gen.h"
#include <esp_task_wdt.h>
#include "enc.h"

#include "parameters.h"
#include <Preferences.h>
Preferences preferences;
ParameterObject parameters;

#include <FastLED.h>

const byte NUM_LEDS = 9;
CRGB targets[NUM_LEDS];
bool smoothFlag[NUM_LEDS];

CRGB leds[NUM_LEDS]; // Array for LEDs on pin 7
CRGB built_in[1]; // Array for LEDs on pin 21
bool startup_leds = true; 

// LSM6 imu;

#include "capsense.h"

/*********************************************
ENCODERS SETUP 
*********************************************/
//encoders rely on the  ESP32Encoder library
//Esp32Encoder rotaryEncoder = Esp32Encoder(18,2,4);//A,B,Button
//optional divider argument
//arguments:
// - A and B: digital inputs from encoder
// - Switch; pin for encoder switch, or -1 for no switch
// - divider: many encoders put out multiple pulses per detent
//   The divider helps to make encoder increments match detents

Esp32Encoder enc[] = {
  Esp32Encoder (43,44,-1,2,50),//A,B,Switch, Divider, CC number
  Esp32Encoder (8,9,-1,2, 51)
};

int monitorInput = -1;
/************** DEFINE INPUTS ******************/
//for potentiometers the first argument is the pin number, the second is a flag if the pot is reversed
Potentiometer pots[] =  {Potentiometer(11)};

//(int ccNumber, int minInterval = 20, int inLow = 0, int inHigh = 127, int deltaThreshold = 2, float alpha = 0.2))
CController cc[] = {
  CController(0, 50, 0, 3000, 10, .1), //pot1
  CController(1, 2, 1900, 2800, 3, .5), //watchdog timer
  CController(2, 20, 0, 2000, 10, .1), //
  CController(3, 20, 0, 500, 10, .1), //touchbar
  CController(4, 20, 0, 500, 10, .1),  //
  //afterTouch for pads 0-7
  CController(10, 20, -127, 127, 1, .5), //7 accelX
  CController(11, 20, -127, 127, 1, .5), //8 accelkY
  CController(12, 20, -127, 127, 1, .5), //9 accelZ
  CController(20, 50, 0, 180, 1, .5), //10 tiltX
  CController(21, 50, 0, 180, 1, .5), //11 tilyY
  CController(22, 50, 0, 180, 1, .5), //12 tiltZ
  CController(30, 20, 0, 127, 1, .5), //13 total magnitude
  CController(17, 20, 0, 127, 1, .8),
};

int velocityDepth = 200;


enum InstrumentMode { MONOPHONIC, POLYPHONIC };
InstrumentMode currentMode = MONOPHONIC;

void setMode(InstrumentMode mode) {
    currentMode = mode;
    //Serial.printf("Switched to %s mode\n", mode == MONOPHONIC ? "Monophonic" : "Polyphonic");
}


/************** SETUP ******************/

void setup() {
  Wire.begin(44,43); 

  FastLED.addLeds<WS2811, 7, RGB>(leds, NUM_LEDS);
  FastLED.addLeds<WS2811, 21, GRB>(built_in, 1);
  FastLED.setBrightness(25);
  leds[0] = CRGB(20, 0, 0);
  leds[1] = CRGB(0, 0, 20);
  built_in[0] = CRGB(0, 0, 20);
  FastLED.show();

  if( ENABLE_USB_MIDI) usbMidiSetup();
  else Serial.begin(115200);
  if( SERIAL_DEBUG) {
    while (!Serial && millis() < 5000) {
    delay(10);
    }
    Serial.println("Serial enabled");
    while(0) {
      Serial.println("Serial enabled");
      delay(100);
    }
  }

  //for(byte i=0;i<2;i++) enc[i].begin([]{enc[0].readEncoder_ISR();});
  enc[0].begin([]{enc[0].readEncoder_ISR();});
  enc[1].begin([]{enc[1].readEncoder_ISR();});
  //imuSetup();


  // Initialize Preferences
    // preferences.begin("params", false); // Open namespace "params" for writing
    // // Load parameters
    // parameters.loadFromPreferences(preferences);
    // // Close Preferences
    // preferences.end();
  
  
  if( ENABLE_USB_MIDI != 1) Serial.println("USB MIDI not enabled");

  //changed from 5,10
  //touchSetCycles(6, 5); //(uint16_t number of measure per cycle, uint16_t sleep, how many cycles to wait before measuring again);
  // touchSetCycles(50,100);
  touchSetCycles( touchChargeTime, touchSleepTime);
  //setupFingeringToMidiNote();
  if( SERIAL_DEBUG) Serial.println("Serial enable");

   // 1. Create configuration structure
  esp_task_wdt_config_t wdt_config = {
    .timeout_ms = 500,           // 0.5-second timeout
    .idle_core_mask = 0,          // Don't monitor idle cores
    .trigger_panic = true         // Reset on timeout
  };
  
  // 2. Initialize with config struct
  esp_task_wdt_init(&wdt_config);
  
  // 3. Add current task to WDT
  esp_task_wdt_add(NULL);

   cc[1].send(127);

}//setup

//LEDS
inline uint8_t map2bitTo8(uint8_t v2) {               // 0..3 → 0..255
  return v2 * 85;                                      // 0,85,170,255
}

inline void decodeVelocity(uint8_t vel, bool &smooth, CRGB &c) {
  smooth = (vel & 0b0100'0000) != 0;
  uint8_t r2 = (vel >> 4) & 0x03;
  uint8_t g2 = (vel >> 2) & 0x03;
  uint8_t b2 = (vel >> 0) & 0x03;
  c = CRGB(map2bitTo8(r2), map2bitTo8(g2), map2bitTo8(b2));
}

// r2,g2,b2 in 0..3, smooth flag true/false → MIDI velocity 0..127
uint8_t packVelocity(uint8_t r2, uint8_t g2, uint8_t b2, bool smooth) {
  r2 &= 0x03; g2 &= 0x03; b2 &= 0x03;
  return (smooth ? 0b0100'0000 : 0) | (r2 << 4) | (g2 << 2) | b2;
}


void handleNoteOn(uint8_t channel, uint8_t note, uint8_t velocity) {  
  /*
  startup_leds = false;
  byte color[][3] = {
    {100, 0, 0},   // Red
    {0, 100, 0},   // Green
    {0, 0, 100},   // Blue
    {100, 0, 100}, // Magenta
    {100, 100, 100} // White
  };
  if (channel < 2) { //Use channels 1 and 2 to change color (velocity is brightness)
    FastLED.setBrightness(velocity);
    leds[channel] = CRGB(color[note % 5][0], color[note % 5][1], color[note % 5][2]);
    FastLED.show();
    Serial.printf("Note On: Channel %d, Note %d, Velocity %d\n", channel + 1, note, velocity);
  }else if(channel < 4){ //Use channels 3 and 4 to flash a light
    FastLED.setBrightness(velocity);
    leds[channel-2] = CRGB(color[note % 5][0], color[note % 5][1], color[note % 5][2]);
    FastLED.show();
    delay(5);
    leds[channel-2] = CRGB(0, 0, 0);
    FastLED.show();
  }
  */

  if (note >= NUM_LEDS) return;

  // MIDI quirk: Note On with velocity 0 == Note Off
  if (velocity == 0) {
    targets[note] = CRGB::Black;
    smoothFlag[note] = true;                           // fade to off
    return;
  }

  bool s; CRGB c;
  decodeVelocity(velocity, s, c);
  targets[note] = c;
  smoothFlag[note] = s;

  if (!s) {
    leds[note] = targets[note];                        // snap instantly
  }
}

void handleNoteOff(uint8_t channel, uint8_t note) {
  if (channel < 2) {
    leds[channel] = CRGB(0, 0, 0);
    FastLED.show();
    Serial.printf("Note Off: Channel %d, Note %d\n", channel + 1, note); 
  }
}

void handleControlChange(uint8_t channel, uint8_t number, uint8_t value) {
  statusLed(1);
  if( number == 100) {ccSendRate = value; return;}

  else if( number == 101) {
    touchChargeTime = (int)value*10;
    touchSetCycles( touchChargeTime, touchSleepTime);
    delay(50);
    resetTouchBaselines();
  } else if( number == 102) {
    touchSleepTime = (int)value*10;
    touchSetCycles( touchChargeTime, touchSleepTime);
    delay(50);  
    resetTouchBaselines();
  } 
  
  else if( number == 110) {
    cc[5].alpha = (float)value/127;
  } else if( number == 111) {
    cc[6].alpha = (float)value/127;
  } else if( number == 112) {
    cc[7].alpha = (float)value/127;
  } 

  else if( number == 127) {
    ESP.restart(); // Clean restart  
  } 

}


/************** LOOP ******************/

byte currentSensor = 0;
int measureCycles = 100;   // Default measure cycles
int sleepCycles = 20;      // Default sleep cycles

void loop() {
  //imuLoop();
  statusLed(0);
  processCCBuffer();

  // Handle MIDI input
  static uint32_t timer = 0;
  int interval = 10; 
  static byte prevValue[] = {0,0,0,0,0};
  static byte num = 0;

  if(millis()-timer > interval){
    timer= millis();
    tickSmoothingDT(interval);
    FastLED.show();

    // handleNoteOn(1, num%10, random(64)+64);
    // num++; 
    
    for(int i=0;i<9;i++){
      cap[i].update();
    }

    for(byte i=0;i<2;i++) readEncoder(i);

    //cc[0].send(analogRead(11));
   // cc[3].send(cap[10].getValue());
    //cc[4].send(cap[9].getValue());
    //cc[5].send(cap[10].getValue());
    
  
    for(int i=0;i<9;i++){
      if( cap[i].state == true && cap[i].getChange() == true){
        sendMidiNoteOn( i, touchToMidi(cap[i].getValue()) );
        // if(startup_leds){
        //   leds[0] = CRGB(255, 0, 0);
        //   leds[1] = CRGB(255, 0, 0);
        // }
        statusLed(2);
        FastLED.show();
      } else if( cap[i].state == false && cap[i].getChange() == true){
        sendMidiNoteOff( i );
        // if(startup_leds){
        //   leds[0] = CRGB(0, 255, 0);
        //   leds[1] = CRGB(0, 255, 0);
        // }
        // FastLED.show();
      }
    }

    esp_task_wdt_reset();
    processIncomingMidi();
  }//timer
        
  return;
}//loop

void readTouchpads() {
  for (int i = 0; i < 11; i++) {
    cap[i].update();
    if( cap[i].state == true && cap[i].getChange() == true){
          if (currentMode == MONOPHONIC) {
                handleMonophonicTouchpad(i, 1);
            } else {
                handlePolyphonicTouchpad(i, 1);
            }
        } else if( cap[i].state == false && cap[i].getChange() == true){
          if (currentMode == MONOPHONIC) {
                handleMonophonicTouchpad(i, 0);
            } else {
                handlePolyphonicTouchpad(i, 0);
            }
        }
  }
}


uint8_t touchToMidi(int val){
  int min = velocityDepth;
  int max = 2000-velocityDepth;
  if(min>max) min = max;
  val = constrain(val,min,max);
  val = map(val, min,max, 0,127);
  return uint8_t(constrain(val,0,127));
}

void resetTouchBaselines() {
  for(int i=0; i<11; i++) {
    for(int j=0; j<100; j++) {
      cap[i].update();
      delay(1);
    }
  }
}

void statusLed(int num){
  byte color[][3] = {
    {100, 0, 0},   // Red
    {0, 100, 0},   // Green
    {0, 0, 100},   // Blue
    {100, 0, 100}, // Magenta
    {100, 100, 100} // White
  };
  static int state = 0;
  static uint32_t timer = 0;
  int interval = 63;
  if( num==0){
    if(state>0){
      if(millis()-timer > interval){
        state = 0;
        built_in[0] = CRGB(0, 0, 0);
        FastLED.show();
      }
      return;
    } else return;
  } 

  if(num>5) return;

  //flash led
  timer = millis();
  state=1;
  built_in[0] = CRGB(color[num-1][0], color[num-1][1], color[num-1][2]);
  FastLED.show();
}

void readEncoder(byte num){
  int val = enc[num].delta(); //get encoder  count
  if(val!= 0){
    if(SERIAL_DEBUG){
      Serial.print("count: ");
      Serial.println(val);
    }
    else{
      sendMidiCC(enc[num].ccNumber, 64+val);
    }
  }
}

// call with milliseconds since last frame (compute via millis())
void tickSmoothingDT(uint16_t dt_ms) {
  // time constant controls “speed” (smaller = faster)
  const float tau_ms = 120.0f; // adjust to taste
  // convert to an 8-bit blend amount ≈ 255*(1 - e^(-dt/tau))
  float frac = 1.0f - expf(-float(dt_ms)/tau_ms);
  uint8_t amt = (uint8_t)constrain(lroundf(frac * 255.0f), 1, 255);

  for (uint16_t i = 0; i < NUM_LEDS; ++i) {
    if (smoothFlag[i]) {
      nblend(leds[i], targets[i], amt);
      if (leds[i] == targets[i]) smoothFlag[i] = false;
    }
  }
}

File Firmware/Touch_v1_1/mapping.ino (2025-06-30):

/*
void interpolateColor(int octave);
void setMode(InstrumentMode mode)
void handleOctaveTouchpad(int touchpadIndex, byte state)
void handleMonoOctaveTouchpad(int touchpadIndex, byte state)
void handleMonophonicTouchpad(int touchpadIndex, byte state)
void handlePolyphonicTouchpad(int touchpadIndex, byte state)
void sendStoredParameters()
CCParameter
*/
struct CCParameter {
    const char* name;   // Parameter name (optional, for debugging/logging)
    int ccNumber;       // Associated MIDI CC number
    int* valuePointer;  // Pointer to the value in ParameterObject
    int minValue;       // Minimum value (scaled)
    int maxValue;       // Maximum value (scaled)
};

// Define the mapping
CCParameter ccParameters[] = {
    {"Lower Threshold 0", 96, &parameters.lowerThresholds[0], 0, 2000},
    {"Lower Threshold 1", 97, &parameters.lowerThresholds[1], 0, 2000},
    {"Upper Threshold 0", 107, &parameters.upperThresholds[0], 0, 2000},
    {"Upper Threshold 1", 108, &parameters.upperThresholds[1], 0, 2000},
    {"Mode", 31, reinterpret_cast<int*>(&parameters.mode), 0, 1},
    {"Polyphonic Note 0", 40, reinterpret_cast<int*>(&parameters.polyphonicNotes[0]), 0, 127},
    {"Smoothing Alpha", 118, &parameters.smoothingAlpha, 0, 65536},
    {"Delta Threshold", 119, &parameters.deltaThreshold, 0, 127},
    // Add more parameters as needed
};
const int numCCParameters = sizeof(ccParameters) / sizeof(CCParameter);

void interpolateColor(int octave);

/**********
MONOPHONIC
**********/

// Define the bit array for touchpad states
unsigned int padState = 0;
int octaveShift = 0;

// Map bit patterns to MIDI notes (default to 0 for unused patterns)
byte fingeringToMidiNote[256] = {0};

// Current active MIDI note
byte currentNote = 0;

// Populate the fingering-to-MIDI note mapping
void setupFingeringToMidiNote() {
    fingeringToMidiNote[0b00000000] = 0;    // No fingers pressed (rest)
    fingeringToMidiNote[0b10000000] = 69;  // Left thumb pressed = A4
    fingeringToMidiNote[0b11000000] = 71;  // Left thumb + index = B4
    fingeringToMidiNote[0b11100000] = 72;  // Left thumb + index + middle = C5
    fingeringToMidiNote[0b11110000] = 74;  // Left thumb + index + middle + ring = D5
    fingeringToMidiNote[0b11111000] = 76;  // Left fingers + right index = E5
    fingeringToMidiNote[0b11111100] = 77;  // Left fingers + right index + middle = F5
    fingeringToMidiNote[0b11111110] = 79;  // Left fingers + right hand = G5
    fingeringToMidiNote[0b11111111] = 81;  // All fingers pressed = A5
}

void handleOctaveTouchpad(int touchpadIndex, byte state) {
    if (touchpadIndex == 9 && state == 1) { // A6 (Octave Up)
        octaveShift += 1;
        Serial.printf("Octave shifted up: %d\n", octaveShift);
    } else if (touchpadIndex == 8 && state == 1) { // A5 (Octave Down)
        octaveShift -= 1;
        Serial.printf("Octave shifted down: %d\n", octaveShift);
    }
    if(octaveShift > 3) octaveShift = 4;
    else if(octaveShift<-3) octaveShift = -4;
    interpolateColor(octaveShift);
}

void handleMonoOctaveTouchpad(int touchpadIndex, byte state) {
    if (touchpadIndex == 9 && state == 1) { // A6 (Octave Up)
        octaveShift = 1;
        Serial.printf("Octave shifted up: %d\n", octaveShift);
    } else if (touchpadIndex == 8 && state == 1) { // A5 (Octave Down)
        octaveShift = -1;
        Serial.printf("Octave shifted down: %d\n", octaveShift);
    }
    else octaveShift = 0;
    interpolateColor(octaveShift);
}

void interpolateColor(int octave) {
    // Map octave range -4 to +4 to interpolation ratio (0.0 to 1.0)
    float ratio = (octave + 4) / 8.0;

    // RGB values for indigo and orange
    int indigo[3] = {75, 0, 130};    // RGB for -4
    int orange[3] = {255, 165, 0};  // RGB for +4
    int rgb[3] = {0,0,0};

    // Interpolate each color component
    for (int i = 0; i < 3; i++) {
        rgb[i] = indigo[i] + ratio * (orange[i] - indigo[i]);
    }

    //leds[0] = CRGB(rgb[0], rgb[1], rgb[2]);
    //FastLED.show();
}
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

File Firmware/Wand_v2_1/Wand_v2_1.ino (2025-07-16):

/*
Wand v2
July 13, 2025
Final wand firmware for Creativitas Summer 2025
*/

const byte ENABLE_USB_MIDI = 1;
const byte SERIAL_DEBUG = 0;

#include <Wire.h>
#include "USB_MIDI.h"
#include "buttons.h"
#include "controller.h"
#include "LSM6.h"
#include "sensor.h"

#include <FastLED.h>
#define NUM_LEDS 10
#define LED_PIN 4
CRGB leds[NUM_LEDS];
CRGB built_in[1]; // Array for LEDs on pin 21
CHSV tipColor = CHSV(160, 255, 255); // Aqua hue
CHSV curColor = CHSV(0,0,0);

LSM6 imu;

float accelX, accelY, accelZ; // Replace with real IMU readings
float accelRest = 0;
float flickThreshold = 1;   // Gs or unit matching your IMU
uint8_t flashBrightness = 0;
// Sensitivity settings (adjust for your IMU and preference)
const float FLICK_THRESHOLD = 0.5; // in g
const uint8_t DECAY_RATE = 20;      // how fast to fade (higher = faster)
uint8_t buttonState[5];
uint8_t buttonIsPressed = 0;

// State variable
uint8_t gradientBrightness = 0; // Current max brightness of tip

uint8_t motionLevel = 0; // 0–255
const uint8_t LEAK_AMOUNT = 25;   // how fast it fades (1–10)
const uint8_t INPUT_GAIN = 255; // scale input motion (adjust as needed)
const float MOTION_SCALE = 1.0; // scale motionMagnitude into 0–1

char report[80];

//IMU DATA PROCESSING

SensorTriple accel;
SensorTriple gyro;

struct SmoothedIMU {
  float accelX, accelY, accelZ;
  float gyroX, gyroY, gyroZ;
};
SmoothedIMU smoothedIMU = {0};
const float smoothingAlpha = 0.1;  // Lower = more smoothing

struct TiltAngles {
  float roll;   // degrees
  float pitch;  // degrees
  float yaw;    // degrees (approximate from tilt)
};
float tiltScaling = 1;
float magnitudeScaling = 1;

struct GyroAngle {
  float x = 0;
  float y = 0;
  float z = 0;
};

GyroAngle integratedGyro;
const float decayFactor = 0.995;  // Closer to 1 = less leak
unsigned long lastTime = 0;

Button buttons[] = {Button(7), Button(8), Button(9), Button(10), Button(0)}; //pin x is the boot button
 
//(int ccNumber, int minInterval = 20, int inLow = 0, int inHigh = 127, int deltaThreshold = 2, float alpha = 0.2))
CController cc[] = {
  CController(0, 50, 10, 4065, 5,   .001, 0.1, 4), //pot1
  CController(1, 50, 10, 4065, 5,   .001, 0.1, 4), //pot2
  CController(2, 20, -100, 100, 5,   .001, 0.01, 4), //magnitude

  CController(10, 20, 0, 180, 5,   .001, 0.01, 4), //3 tilt 10
  CController(11, 20, 0, 180, 5,   .001, 0.01, 4),  //roll
  CController(12, 20, 0, 180, 5,   .001, 0.01, 4), //yaw

  CController(20, 20, -20000, 20000, 5,   .1, 0.01, 4), //6 accel 20
  CController(21, 20, -20000, 20000, 5,   .1, 0.01, 4),  //
  CController(22, 20, -20000, 20000, 5,   .1, 0.01, 4), //

  CController(30, 20, -20000, 20000, 5,   .1, 0.01, 4), //9 gyro 30
  CController(31, 20, -20000, 20000, 5,   .1, 0.01, 4),  //
  CController(32, 20, -20000, 20000, 5,   .1, 0.01, 4), //

  CController(40, 50, -10000, 10000, 5,   .1, 0.01, 4), //12 angle 40
  CController(41, 50, -10000, 10000, 5,   .1, 0.01, 4),  //
  CController(42, 50, -10000, 10000, 5,   .1, 0.01, 4), //
};

void setup()
{
  if( ENABLE_USB_MIDI) usbMidiSetup();
  else Serial.begin(115200);

  Wire.begin(6,5);

  if (!imu.init())
  {
    Serial.println("Failed to detect and initialize IMU!");
    while (1);
  }
  imu.enableDefault();
  delay(100);
  imu.read();
  accelRest = calcMagnitude();

  if( ENABLE_USB_MIDI != 1) Serial.println("USB MIDI not enabled");

  FastLED.addLeds<WS2811, LED_PIN, RGB>(leds, NUM_LEDS);//.setCorrection( TypicalLEDStrip );
  FastLED.addLeds<WS2811, 21, GRB>(built_in, 1);
  FastLED.clear();
  built_in[0] = CRGB(0, 0, 20);
  FastLED.show();
  FastLED.setBrightness(255);  // Max brightness
}

void loop()
{
  readButtons();
  processIncomingMidi();

  static uint32_t timer = 0;
  int interval = 2; 

  if(millis()-timer > interval){
    timer= millis();

    statusLed(0);
    imu.read(); 
    accel.update(imu.a.x, imu.a.y, imu.a.z);
    gyro.update(imu.g.x, imu.g.y, imu.g.z);

    float magnitude = calcMagnitude();
    TiltAngles angles = computeTiltAngles(imu.a.x, imu.a.y, imu.a.z);
    calcDrumStrike(magnitude);

    updateLeakyGradient(magnitude, getBaseColorFromButtons());


    cc[0].send(analogRead(1));
    cc[1].send(analogRead(2));
    if(buttonIsPressed == 0) return

    cc[2].send(int(magnitude * 100));

    if( tiltScaling > 0.01 ) cc[3].send(angles.roll * tiltScaling);
    if( tiltScaling > 0.01 ) cc[4].send(angles.pitch * tiltScaling);
    if( tiltScaling > 0.01 ) cc[5].send(angles.yaw * tiltScaling); 

    if( accel.x.rawScale > 0.01 ) cc[6].send(accel.x.getScaledSmoothed());
    if( accel.y.rawScale > 0.01 ) cc[7].send(accel.y.getScaledSmoothed());
    if( accel.z.rawScale > 0.01 ) cc[8].send(accel.z.getScaledSmoothed());

    if( gyro.x.rawScale > 0.01 )  cc[9].send(gyro.x.getScaledSmoothed());
    if( gyro.x.rawScale > 0.01 ) cc[10].send(gyro.y.getScaledSmoothed());
    if( gyro.x.rawScale > 0.01 ) cc[11].send(gyro.z.getScaledSmoothed());

    if( gyro.x.integratedScale > 0.01 )  cc[12].send(gyro.x.getScaledIntegrated());
    if( gyro.x.integratedScale > 0.01 ) cc[13].send(gyro.y.getScaledIntegrated());
    if( gyro.x.integratedScale > 0.01 ) cc[14].send(gyro.z.getScaledIntegrated());
  }
} // LOOP

void readButtons(){
  byte midiNotes[] = {60,62,64,65,72};
  buttonIsPressed = 0;

  for(int i=0;i<5;i++){
    buttons[i].loop();
    if(buttons[i].isPressed()){
      gyro.resetIntegrated();
      accel.resetIntegrated();

      sendButtonPress(midiNotes[i], 127);
      buttonIsPressed = 1;
    } else if( buttons[i].isReleased()){
      sendButtonPress(midiNotes[i], 0);
    } else if( buttons[i].isDown()) {
      buttonIsPressed = 1;
    }
  }

}

float calcMagnitude(){
  // sensitivity = 0.000061 for ±2g (default)
  // use 0.000122 for ±4g, etc.
  const float ACCEL_SENSITIVITY = 0.000061;

  float ax_g = imu.a.x * ACCEL_SENSITIVITY;
  float ay_g = imu.a.y * ACCEL_SENSITIVITY;
  float az_g = imu.a.z * ACCEL_SENSITIVITY;

  return sqrt(ax_g * ax_g + ay_g * ay_g + az_g * az_g) - accelRest;
}
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

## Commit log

2024-06-20 initial gerbers
    [ESP32_MIDI-B_Cu.gbl, ESP32_MIDI-B_Mask.gbs, ESP32_MIDI-B_Paste.gbp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]
2024-06-27 update PCBs
2024-07-09 adding v2 PCB
    [ESP32_MIDI_v2-B_Cu.gbl, ESP32_MIDI_v2-B_Mask.gbs, ESP32_MIDI_v2-B_Paste.gbp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]
2024-07-09 Adding simple IMU sketches
2024-07-09 update folder structure
    [ESP32_MIDI-B_Cu.gbl, ESP32_MIDI-B_Mask.gbs, ESP32_MIDI-B_Paste.gbp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]
2024-07-09 Added enclosure elements
    [1590BB.stl, 1590BB_cover3.stl, 1590BB_cover3b.stl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]
2024-07-09 Update PCB files
    [ESP32_MIDI-B_Cu.gbl, ESP32_MIDI-B_Mask.gbs, ESP32_MIDI-B_Paste.gbp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]
2024-07-11 update firmware and faceplates
    [1590BB_cover3b-LED.stl, 1590BB_cover3b-noLed.stl, 1590BB_cover3b.stl]
2024-07-11 Create readme.md
    To Do:
    - add link for Arduino installer
    - add link for esp32 definition
2024-07-15 Updating enclosures
    [1590BB_cover3-Top_002.stl, 1590BB_cover3.stl, 1590BB_cover3b-LED.stl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]
2024-07-15 session 1 notes
    [USB-C_port.blend, USB-C_port.stl, USB-C_port_13mm-Port.stl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]
2024-07-16 limit sending IMU data
2024-12-20 Jan 24 v1
    [ESP32_MIDI_v3.kicad_pro-B_Cu.gbl, ESP32_MIDI_v3.kicad_pro-B_Mask.gbs, ESP32_MIDI_v3.kicad_pro-B_Paste.gbp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]
2025-01-10 Jan 10 commit - up to v4
    [ESP32_MIDI_v3a-B_Cu.gbl, ESP32_MIDI_v3a-B_Mask.gbs, ESP32_MIDI_v3a-B_Paste.gbp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]
2025-01-13 kicad refresh
    [ESP32_MIDI_v3a.kicad_pcb, ESP32_MIDI_v3a.kicad_sch]
2025-01-20 Switched to new library and added LED midi messages
2025-01-24 Added back led responsiveness on startup
2025-06-30 added wand and barre
    [ESP32_MIDI.step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]
2025-07-03 update all kicad designs for week 1
    [ESP32_MIDI.step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]
2025-07-11 files Jul 10
    [Sum25_Wand_v2.kicad_sch]
2025-07-13 semifinal code for summer25
    [Wand.3mf]
2025-07-23 added touch v1_1
    [ESP32_MIDI_Summer25_FRETS_v2_5.kicad_pcb.kicad_sch]
2025-07-27 July 26 gerbers
    [ESP32_MIDI_Summer25_FRETS_v2_5.kicad_pcb-B_Cu.gbl, ESP32_MIDI_Summer25_FRETS_v2_5.kicad_pcb-B_Mask.gbs, ESP32_MIDI_Summer25_FRETS_v2_5.kicad_pcb-B_Paste.gbp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]
2025-07-31 tweaking capsense settings and imu values
2025-08-03 added support for BMI160
    [Barre hooks V3.stl, Fret Stands.stl, Hooks V5 (1).stl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]
2025-09-01 add USB device name
2025-09-01 robin and strip PCB updates
2026-02-26 lots of pcb updates!
    [DC12V_A-B_Cu.gbl, DC12V_A-B_Mask.gbs, DC12V_A-B_Paste.gbp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]
